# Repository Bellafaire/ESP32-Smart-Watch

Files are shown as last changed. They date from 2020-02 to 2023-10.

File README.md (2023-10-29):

# ESP32 Smartwatch
This project is a fully open source smartwatch based around the ESP32, the project is ongoing for updates see the hackaday.io page for this project (https://hackaday.io/project/168227-custom-smartwatch).
The goal of this project is to create a smartwatch that is easy to reprogram and use as an IOT controller or just as a DIY fashion statement.  
Serial communication and charging are handled on-board through a single micro-usb connector without any external dock. 
The watch is built around the ESP32 WROOM module and is programable using the espressif or Arduino IDE. 
Using the ESP32 allows for the user to develop their software while leveraging the open-source libraries and examples that are available online for quick development.

## Companion App 
The companion android app that allows the smartwatch to control media and obtain phone notifications has been split to a seperate repo and can be found [here](https://github.com/Bellafaire/Android-Companion-App-For-BLE-Devices) along with an example sketch for bluetooth interfacing using the ESP32. 
The app can be downloaded from the releases tab of the provided repo, the V1 watch firmware works only with app releases up to 1.2.0. 
For firmware versions 2 and 3 releases after 2.0.0 must be used, releases after this version use a different communication structure that has proved to be more reliable. 

## Firmware Versions
There are 3 versions of the firmware available for this project. Only V3 is in active development. 
The V1 firmware utilizes deep sleep along with the V1 android companion app, this firmware works well enough and offers the greatest power savings over any of the other options. 
V2 is a bit more animated, boasting some additional applications along with the switch to light sleep which enables faster wakeup from tap or by performing a wrist gesture. 

V3 is the current firmware, it is much more stable and expandable. 
The current V3 firmware supports: 
- App icons on home screen, tap to view the tagline of the notification
- Spotify control through tapping the spotify app icon
- built in calculator 
- Improved UI and tools to aid feature expansion. 

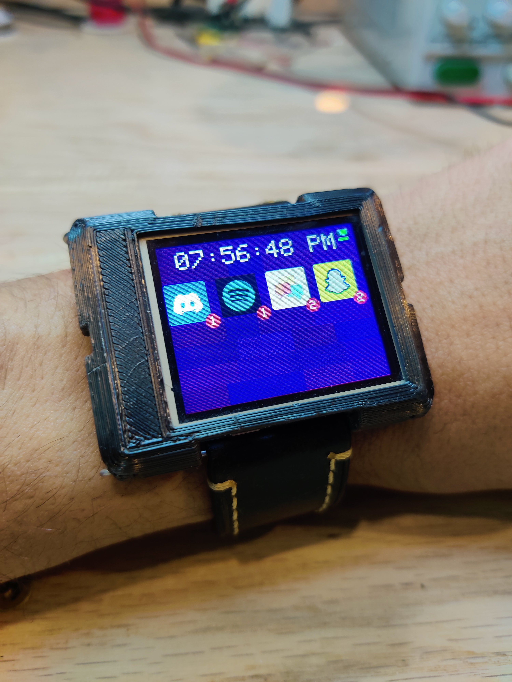
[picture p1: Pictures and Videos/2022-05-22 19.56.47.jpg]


The case is 3D printed and designed in FreeCAD, the design files are available in this repo. 

### Dependencies 
If you're working with the V3 Firmware, then you will need the following dependencies, you can get these through the Arduino IDE library manager: 
- Adafruit GFX Version 1.11.9 By Adafruit
- Adafruit ST7735 and ST7789 Library Version 1.10.3 By Adafruit
- base64 Version 1.30 by Densaugeo 

Other versions of the above dependencies **will most likely work** but have not been tested on this hardware. 

## Hardware Versions
The current hardware version for the watch is V5 which provides a more slim design while maintaining all the features of V4. 

## Video Updates about the project

[Video Update #5](https://www.youtube.com/watch?v=LVs-HgjjFUM)

[Video Update #4](https://www.youtube.com/watch?v=E8-lO0pQunM)

[Video Update #3](https://www.youtube.com/watch?v=vvuce4NQqrk)

[Video Update #2](https://www.youtube.com/watch?v=UNLAq5FuJq4)

[Video Update #1](https://www.youtube.com/watch?v=IoVqdB_q3pE)

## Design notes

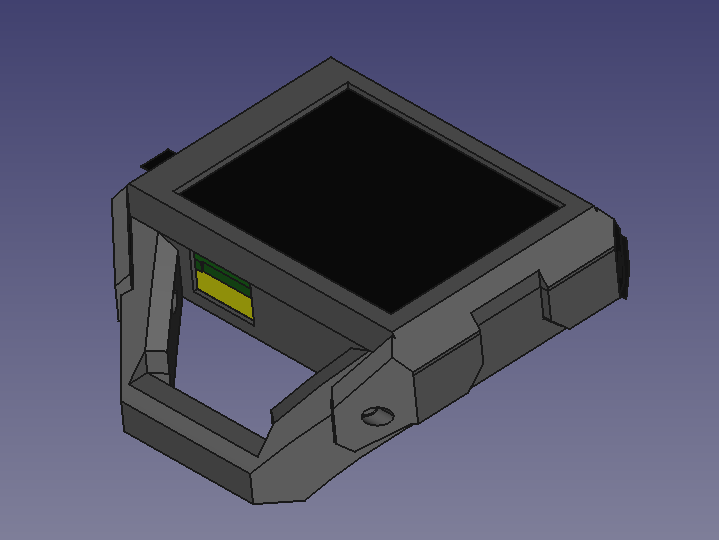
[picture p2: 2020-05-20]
Pictures and Videos/smartwatch V4 Case.png

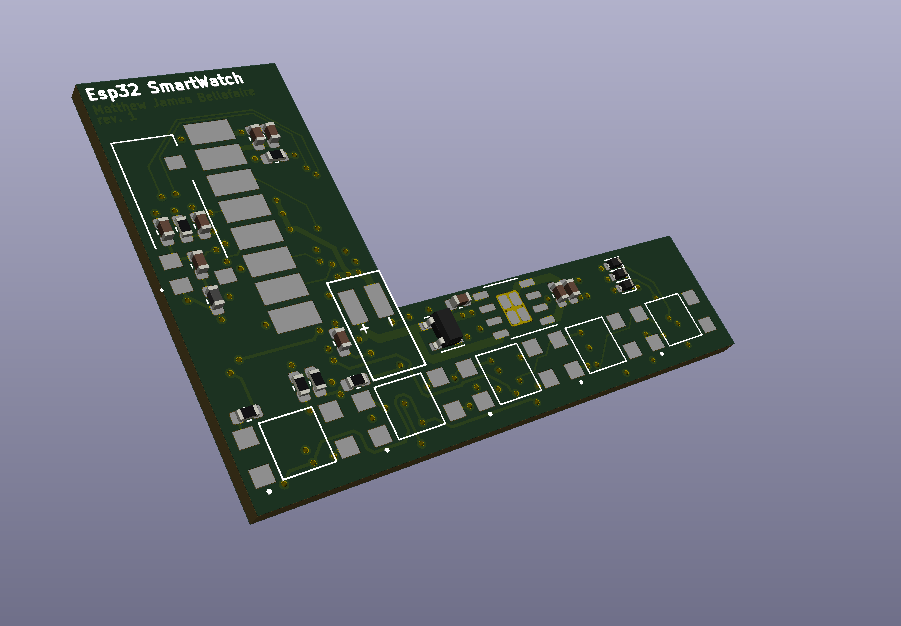
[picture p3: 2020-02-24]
Pictures and Videos/Screenshot_1.png

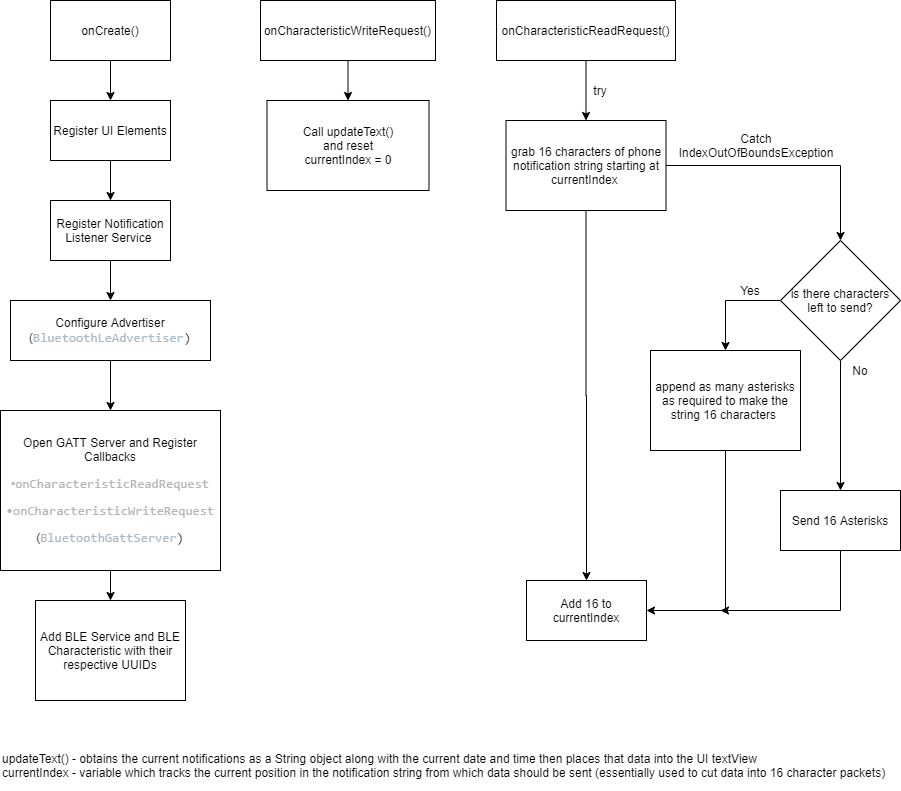
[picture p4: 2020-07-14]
Pictures and Videos/Android App GATT Flowchart.png

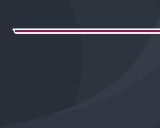
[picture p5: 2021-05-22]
Misc. Files/BACKGROUND.png

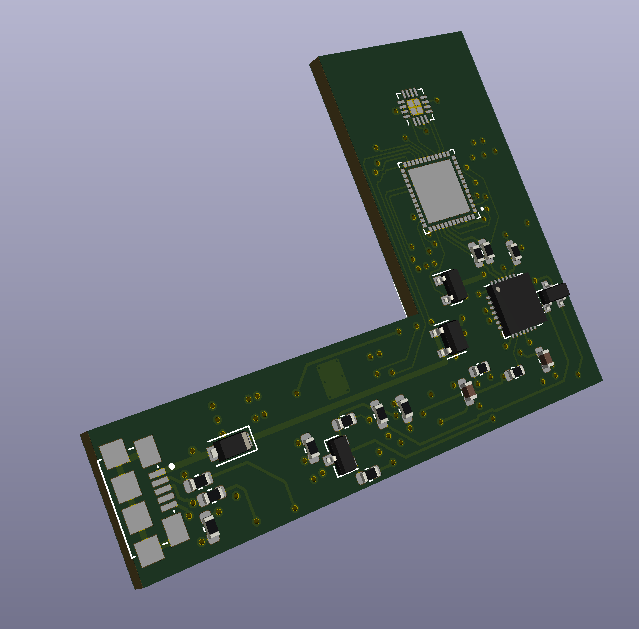
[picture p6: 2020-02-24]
Pictures and Videos/Screenshot_2.png

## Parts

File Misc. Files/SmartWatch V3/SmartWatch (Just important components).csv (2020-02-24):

Qty | Reference(s) | Value | LibPart | Footprint | Datasheet | DigiKey Part Number
1 | ANT1 | W3008 | SmartWatch-rescue:W3008 | SmartWatch:ANTENNA_W3008 | Manufacturer recommendations | 553-1530-1-ND
2 | C1, C2 | 10nF | Device:C | Capacitor_SMD:C_0603_1608Metric | ~ | 399-7842-1-ND
25 | C3, C20 | 10uF | Device:C | Capacitor_SMD:C_0603_1608Metric | ~ | 478-10766-1-ND
50 | C5, C7, C9, C11, C15, C16, C17, C18, C19 | 0.1u | Device:C | Capacitor_SMD:C_0603_1608Metric | ~ | 1276-1258-1-ND
3 | ESP1 | ESP32PICO_D4-esp32pico_d4 | SmartWatch-rescue:ESP32PICO_D4-esp32pico_d4 | SmartWatch:ESP32_D4_PICO_HAND_SOLDER |  | 1904-1029-1-ND
50 | Q1, Q2 | MMBT3904 | Transistor_BJT:MMBT3904 | Package_TO_SOT_SMD:SOT-23 | https://www.fairchildsemi.com/datasheets/2N/2N3904.pdf | MMBT3904TPMSCT-ND
6 | R1, R2, R3, R4, R8, R19 | 0R | Device:R | Resistor_SMD:R_0603_1608Metric | ~ | 311-0.0GRCT-ND
8 | R5, R6, R7, R11, R13, R14, R15, R16 | 10k | Device:R | Resistor_SMD:R_0603_1608Metric | ~ | 311-10KGRCT-ND
2 | R9, R10 | 27 | Device:R | Resistor_SMD:R_0603_1608Metric | ~ | 311-27.0HRCT-ND
1 | R12 | 47k | Device:R | Resistor_SMD:R_0603_1608Metric | ~ | 311-47GRCT-ND
10 | SW1, SW2 | EVQ-P7J01P | SmartWatch-rescue:EVQ-P7J01P | SmartWatch:SW_EVQ-P7J01P | Panasonic | P16767CT-ND
2 | U1 | S-13A1A33-E8T1U3 | SmartWatch-rescue:S-13A1A33-E8T1U3 | Package_SO:HSOP-8-1EP_3.9x4.9mm_P1.27mm_EP2.41x3.1mm_ThermalVias | https://www.ablic.com/en/doc/datasheet/voltage_regulator/S13A1_E.pdf | 1662-2801-1-ND
3 | U3 | FT231XS | Interface_USB:FT231XS | Package_SO:SSOP-20_3.9x8.7mm_P0.635mm | http://www.ftdichip.com/Products/ICs/FT231X.html | 768-1129-1-ND

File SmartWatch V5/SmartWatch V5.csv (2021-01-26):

Item | Qty | Reference(s) | Value | LibPart | Footprint | Datasheet | Field4 | Field5 | Field6 | Field7 | Field8 | digikey
1 | 1 | A1 | ZJY117 | CustomParts:ZJY117 | CustomFootprints:ZJY117 | https://www.icbanq.com/icdownload/data/ICBShop/Board/ZJY117-1.8_18P%20TFT%20LCD%20With%20Touch%20Panel.pdf
2 | 11 | C1, C4, C5, C6, C7, C9, C10, C12, C13, C14, C15 | 10uF | Device:C | Capacitor_SMD:C_0603_1608Metric | ~ |  |  |  |  |  | 478-10766-1-ND
3 | 4 | C2, C3, C8, C11 | 0.1uF | Device:C | Capacitor_SMD:C_0603_1608Metric | ~ |  |  |  |  |  | 1276-1006-1-ND
4 | 1 | D1 | FSV340FP | Device:D_Schottky | Diode_SMD:D_SOD-123 | https://www.onsemi.com/pub/Collateral/FSV360FP-D.PDF |  |  |  |  |  | FSV340FPCT-ND
5 | 3 | D2, D3, D4 | ESDZV5-1BF4 | Device:D_TVS | Diode_SMD:D_0201_0603Metric | https://www.st.com/content/ccc/resource/technical/document/datasheet/group3/3b/a1/d0/ee/47/bb/49/64/DM00344091/files/DM00344091.pdf/jcr:content/translations/e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 |  |  |  |  |  | 497-17318-1-ND
6 | 1 | J1 | 10118192-0001LF | CustomParts:10118192-0001LF | CustomFootprints:AMPHENOL_10118192-0001LF | Amphenol ICC | None | Single Port 5 Contact Horizontal Right Angle Shielded Micro B USB 2.0 Connector | 609-4613-1-ND | 10118192-0001LF | https://www.digikey.com/product-detail/en/amphenol-icc-fci/10118192-0001LF/609-4613-1-ND/2785378 | 609-4613-1-ND
7 | 1 | J2 |  | Connector:Conn_01x02_Female | CustomFootprints:BATTERY | ~
8 | 3 | J8, J9, J10 | TestPad | CustomParts:TestPad | CustomFootprints:TESTPAD
9 | 1 | Q1 | FDN340P | Device:Q_PMOS_GSD | Package_TO_SOT_SMD:SOT-23 | https://www.onsemi.com/pub/Collateral/FDN340P-D.PDF |  |  |  |  |  | FDN340PCT-ND
10 | 2 | Q2, Q3 | MMBT3904 | Device:Q_NPN_BEC | Package_TO_SOT_SMD:SOT-23 | https://assets.nexperia.com/documents/data-sheet/MMBT3904.pdf |  |  |  |  |  | 1727-4044-1-ND
11 | 2 | Q5, Q6 | FDN028N20 | Device:Q_NMOS_GSD | Package_TO_SOT_SMD:SOT-23 | https://www.onsemi.com/pub/Collateral/FDN028N20-D.pdf |  |  |  |  |  | FDN028N20OSCT-ND
12 | 3 | R1, R7, R21 | 100k | Device:R | Resistor_SMD:R_0603_1608Metric | ~ |  |  |  |  |  | CR0603-JW-104ELFCT-ND
13 | 2 | R2, R3 | 27 | Device:R | Resistor_SMD:R_0603_1608Metric | ~ |  |  |  |  |  | RMCF0603JT27R0CT-ND
14 | 13 | R6, R9, R10, R13, R14, R15, R16, R17, R18, R19, R20, R22, R24 | 10k | Device:R | Resistor_SMD:R_0603_1608Metric | ~ |  |  |  |  |  | 311-10.0KCRCT-ND
15 | 1 | R8 | 0 (NC) | Device:R | Resistor_SMD:R_0603_1608Metric | ~ |  |  |  |  |  | 311-0.0GRCT-ND
16 | 1 | R23 | 10m | Device:R | Resistor_SMD:R_0805_2012Metric | https://d1d2qsbl8m0m72.cloudfront.net/en/products/databook/datasheet/passive/resistor/chip_resistor/pmr-e.pdf |  |  |  |  |  | RL12T.010JCT-ND
17 | 2 | SW1, SW2 | EVQ-P7J01P | CustomParts:EVQ-P7J01P | CustomFootprints:SW_EVQ-P7J01P | Panasonic | Manufacturer Recommendation |  |  |  |  | P16767CT-ND
18 | 1 | TH1 | NXFT15XH103FA2B100 | Device:Thermistor | Connector_PinHeader_1.00mm:PinHeader_1x02_P1.00mm_Vertical | https://www.murata.com/~/media/webrenewal/support/library/catalog/products/thermistor/ntc/r44e.ashx?la=en-us |  |  |  |  |  | 490-5630-ND
19 | 1 | U1 | MAX17260 | CustomParts:MAX17260 | CustomFootprints:TDFN16-EP | https://datasheets.maximintegrated.com/en/ds/MAX17260.pdf |  |  |  |  |  | 175-MAX17260SEWL+TCT-ND
20 | 1 | U2 | FT231XQ | Interface_USB:FT231XQ | Package_DFN_QFN:QFN-20-1EP_4x4mm_P0.5mm_EP2.5x2.5mm | https://www.ftdichip.com/Support/Documents/DataSheets/ICs/DS_FT231X.pdf |  |  |  |  |  | 768-1128-1-ND
21 | 1 | U3 | LP5912-3.3DRVT | CustomParts:LP5912-3.3DRVT | Package_SON:WSON-6-1EP_2x2mm_P0.65mm_EP1x1.6mm_ThermalVias | http://www.ti.com/lit/ds/symlink/lp5912.pdf |  |  |  |  |  | 296-44153-1-ND
22 | 1 | U5 | MCP73832-2-OT | Battery_Management:MCP73832-2-OT | Package_TO_SOT_SMD:SOT-23-5 | http://ww1.microchip.com/downloads/en/DeviceDoc/20001984g.pdf |  |  |  |  |  | MCP73832T-2ACI/OTCT-ND
23 | 1 | U6 | ESP32-WROOM-32 | RF_Module:ESP32-WROOM-32 | RF_Module:ESP32-WROOM-32 | https://www.espressif.com/sites/default/files/documentation/esp32-wroom-32_datasheet_en.pdf |  |  |  |  |  | 1904-1010-1-ND
24 | 1 | U8 | ADXL337 | CustomParts:ADXL337 | CustomFootprints:ADXL337BCPZ-RL | https://www.analog.com/media/en/technical-documentation/data-sheets/ADXL337.pdf |  |  |  |  |  | ADXL337BCPZ-RLCT-ND
25 | 1 | U10 | TSC2003IPWR | CustomParts:TSC2003IPWR | Package_SO:TSSOP-16_4.4x5mm_P0.65mm | http://www.ti.com/lit/ds/symlink/tsc2003.pdf |  |  |  |  |  | 296-14340-1-ND
26 | 1 |  | LP502030JH |  |  | https://www.jauch.com/downloadfile/5bf52a1a232e7aaef7e84c3116561e20c/250mah_-_lp502030jh_1s1p_2_wire_50mm.pdf |  |  |  |  |  | 1908-1353-ND

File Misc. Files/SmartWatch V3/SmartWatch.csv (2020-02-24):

Source: | J:\Dropbox\Dropbox\Lab Projects\Smart Watch\SmartWatch V3\SmartWatch.sch
Date: | 1/13/2020 8:32:21 AM
Tool: | Eeschema (5.0.1)-3
Generator: | C:\Program Files\KiCad\bin\scripting\plugins/bom_csv_grouped_by_value.py
Component Count: | 58
Individual Components:
Item | Qty | Reference(s) | Value | LibPart | Footprint | Datasheet | DigiKey Part Number | Field4 | Field5 | Field6 | Field7 | Field8 | digikey
 |  | ANT1 | W3008 | SmartWatch-rescue:W3008 | SmartWatch:ANTENNA_W3008 | Manufacturer recommendations |  | PulseLarsen Antennas |  |  |  |  | 553-1530-1-ND
 |  | C1 | 10nF | Device:C | Capacitor_SMD:C_0603_1608Metric | ~ | 399-7842-1-ND
 |  | C2 | 10nF | Device:C | Capacitor_SMD:C_0603_1608Metric | ~ | 399-7842-1-ND
 |  | C3 | 10uF | Device:C | Capacitor_SMD:C_0603_1608Metric | ~ | 478-10766-1-ND
 |  | C4 | 0.1uF | Device:C | Capacitor_SMD:C_0603_1608Metric | ~ | 1276-1258-1-ND
 |  | C5 | 0.1u | Device:C | Capacitor_SMD:C_0603_1608Metric | ~ | 1276-1258-1-ND
 |  | C6 | 0.1u (NC) | Device:C | Capacitor_SMD:C_0603_1608Metric | ~ | 1276-1258-1-ND
 |  | C7 | 0.1u | Device:C | Capacitor_SMD:C_0603_1608Metric | ~ | 1276-1258-1-ND
 |  | C8 | 47p | Device:C | Capacitor_SMD:C_0603_1608Metric | ~ | 311-1065-1-ND
 |  | C9 | 0.1u | Device:C | Capacitor_SMD:C_0603_1608Metric | ~ | 1276-1258-1-ND
 |  | C10 | 10u | Device:C | Capacitor_SMD:C_0603_1608Metric | ~ | 478-10766-1-ND
 |  | C11 | 0.1u | Device:C | Capacitor_SMD:C_0603_1608Metric | ~ | 1276-1258-1-ND
 |  | C12 | TBD | Device:C | Capacitor_SMD:C_0603_1608Metric | ~ | 1276-1258-1-ND
 |  | C13 | TBD | Device:C | Capacitor_SMD:C_0603_1608Metric | ~ | 1276-1258-1-ND
 |  | C14 | 47p | Device:C | Capacitor_SMD:C_0603_1608Metric | ~ | 311-1065-1-ND
 |  | C15 | 0.1u | Device:C | Capacitor_SMD:C_0603_1608Metric | ~ | 1276-1258-1-ND
 |  | C16 | 0.1u | Device:C | Capacitor_SMD:C_0603_1608Metric | ~ | 1276-1258-1-ND
 |  | C17 | 0.1u | Device:C | Capacitor_SMD:C_0603_1608Metric | ~ | 1276-1258-1-ND
 |  | C18 | 0.1u | Device:C | Capacitor_SMD:C_0603_1608Metric | ~ | 1276-1258-1-ND
 |  | C19 | 0.1u | Device:C | Capacitor_SMD:C_0603_1608Metric | ~ | 1276-1258-1-ND
 |  | C20 | 10uF | Device:C | Capacitor_SMD:C_0603_1608Metric | ~ | 478-10766-1-ND
 |  | D2 | FSV340FP | Device:D_Schottky | Diode_SMD:D_SOD-123F | https://www.onsemi.com/pub/Collateral/FSV360FP-D.PDF | FSV340FPCT-ND
 |  | ESP1 | ESP32PICO_D4-esp32pico_d4 | SmartWatch-rescue:ESP32PICO_D4-esp32pico_d4 | SmartWatch:ESP32_D4_PICO_HAND_SOLDER
 |  | J1 | 10118192-0001LF | SmartWatch-rescue:10118192-0001LF | SmartWatch:AMPHENOL_10118192-0001LF | Amphenol ICC | 609-4613-1-ND | None | Single Port 5 Contact Horizontal Right Angle Shielded Micro B USB 2.0 Connector | 609-4613-1-ND | 10118192-0001LF | https://www.digikey.com/product-detail/en/amphenol-icc-fci/10118192-0001LF/609-4613-1-ND/2785378
 |  | J2 | Bat_in | Connector:Conn_01x02_Female | SmartWatch:BATTERY | ~
 |  | J3 | TEST_PAD | SmartWatch-rescue:TEST_PAD | SmartWatch:TEST_PAD
 |  | J4 | TEST_PAD | SmartWatch-rescue:TEST_PAD | SmartWatch:TEST_PAD
 |  | J5 | TEST_PAD | SmartWatch-rescue:TEST_PAD | SmartWatch:TEST_PAD
 |  | J6 | TEST_PAD | SmartWatch-rescue:TEST_PAD | SmartWatch:TEST_PAD
 |  | L1 | TBD | Device:L | Inductor_SMD:L_0603_1608Metric | ~
 |  | Q1 | MMBT3904 | Transistor_BJT:MMBT3904 | Package_TO_SOT_SMD:SOT-23 | https://www.fairchildsemi.com/datasheets/2N/2N3904.pdf |  |  |  |  |  |  | MMBT3904TPMSCT-ND
 |  | Q2 | MMBT3904 | Transistor_BJT:MMBT3904 | Package_TO_SOT_SMD:SOT-23 | https://www.fairchildsemi.com/datasheets/2N/2N3904.pdf |  |  |  |  |  |  | MMBT3904TPMSCT-ND
 |  | Q3 | FDN340P | Device:Q_PMOS_DGS | Package_TO_SOT_SMD:SOT-23 | ~ | FDN340PCT-ND
 |  | R1 | 0R | Device:R | Resistor_SMD:R_0603_1608Metric | ~ | 311-0.0GRCT-ND
 |  | R2 | 0R | Device:R | Resistor_SMD:R_0603_1608Metric | ~ | 311-0.0GRCT-ND
 |  | R3 | 0R | Device:R | Resistor_SMD:R_0603_1608Metric | ~ | 311-0.0GRCT-ND
 |  | R4 | 0R | Device:R | Resistor_SMD:R_0603_1608Metric | ~ | 311-0.0GRCT-ND
 |  | R5 | 10k | Device:R | Resistor_SMD:R_0603_1608Metric | ~ | 311-10KGRCT-ND
 |  | R6 | 10k | Device:R | Resistor_SMD:R_0603_1608Metric | ~ | 311-10KGRCT-ND
 |  | R7 | 10k | Device:R | Resistor_SMD:R_0603_1608Metric | ~ | 311-10KGRCT-ND
 |  | R8 | 0R | Device:R | Resistor_SMD:R_0603_1608Metric | ~ | 311-0.0GRCT-ND
 |  | R9 | 27 | Device:R | Resistor_SMD:R_0603_1608Metric | ~ | 311-27.0HRCT-ND
 |  | R10 | 27 | Device:R | Resistor_SMD:R_0603_1608Metric | ~ | 311-27.0HRCT-ND
 |  | R11 | 10k | Device:R | Resistor_SMD:R_0603_1608Metric | ~ | 311-10KGRCT-ND
 |  | R12 | 47k | Device:R | Resistor_SMD:R_0603_1608Metric | ~ | 311-47GRCT-ND
 |  | R13 | 10k | Device:R | Resistor_SMD:R_0603_1608Metric | ~ | 311-10KGRCT-ND
 |  | R14 | 10k | Device:R | Resistor_SMD:R_0603_1608Metric | ~ | 311-10KGRCT-ND
 |  | R15 | 10k | Device:R | Resistor_SMD:R_0603_1608Metric | ~ | 311-10KGRCT-ND
 |  | R16 | 10k | Device:R | Resistor_SMD:R_0603_1608Metric | ~ | 311-10KGRCT-ND
 |  | R19 | 0R | Device:R | Resistor_SMD:R_0603_1608Metric | ~ | 311-0.0GRCT-ND
 |  | SW1 | EVQ-P7J01P | SmartWatch-rescue:EVQ-P7J01P | SmartWatch:SW_EVQ-P7J01P | Panasonic |  | Manufacturer Recommendation |  |  |  |  | P16767CT-ND
 |  | SW2 | EVQ-P7J01P | SmartWatch-rescue:EVQ-P7J01P | SmartWatch:SW_EVQ-P7J01P | Panasonic |  | Manufacturer Recommendation |  |  |  |  | P16767CT-ND
 |  | U1 | S-13A1A33-E8T1U3 | SmartWatch-rescue:S-13A1A33-E8T1U3 | Package_SO:HSOP-8-1EP_3.9x4.9mm_P1.27mm_EP2.41x3.1mm_ThermalVias | https://www.ablic.com/en/doc/datasheet/voltage_regulator/S13A1_E.pdf | 1662-2801-1-ND
 |  | U2 | LCD_TOUCH | SmartWatch-rescue:LCD_TOUCH | Connector_PinHeader_2.54mm:PinHeader_2x06_P2.54mm_Vertical | https://usa.banggood.com/1_8-Inch-LCD-Screen-SPI-Serial-Port-Module-TFT-Color-Display-Touch-Screen-ST7735-For-Arduino-p-1414465.html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
 |  | U3 | FT231XS | Interface_USB:FT231XS | Package_SO:SSOP-20_3.9x8.7mm_P0.635mm | http://www.ftdichip.com/Products/ICs/FT231X.html |  |  |  |  |  |  | 768-1129-1-ND
 |  | U4 | MAX9065 | SmartWatch-rescue:MAX9065 | Package_TO_SOT_SMD:SOT-23-5 | https://datasheets.maximintegrated.com/en/ds/MAX9065.pdf | MAX9065EUK+TCT-ND
 |  | U5 | MCP73811T-420I-OT | Battery_Management:MCP73811T-420I-OT | Package_TO_SOT_SMD:SOT-23-5 | http://ww1.microchip.com/downloads/en/DeviceDoc/22036b.pdf | MCP73811T-420I/OTCT-ND
 |  | U7 | ADXL337 | SmartWatch-rescue:ADXL337 | SmartWatch:LFCSP-16-1EP_3x3mm_P0.5mm_EP1.6x1.6mm | https://www.analog.com/media/en/technical-documentation/data-sheets/ADXL337.pdf | ADXL337BCPZ-RL7CT-ND
Collated Components:
Item | Qty | Reference(s) | Value | LibPart | Footprint | Datasheet | DigiKey Part Number | Field4 | Field5 | Field6 | Field7 | Field8 | digikey
1 | 1 | ANT1 | W3008 | SmartWatch-rescue:W3008 | SmartWatch:ANTENNA_W3008 | Manufacturer recommendations |  | PulseLarsen Antennas |  |  |  |  | 553-1530-1-ND
2 | 2 | C1, C2 | 10nF | Device:C | Capacitor_SMD:C_0603_1608Metric | ~ | 399-7842-1-ND
3 | 2 | C3, C20 | 10uF | Device:C | Capacitor_SMD:C_0603_1608Metric | ~ | 478-10766-1-ND
4 | 1 | C4 | 0.1uF | Device:C | Capacitor_SMD:C_0603_1608Metric | ~ | 1276-1258-1-ND
5 | 9 | C5, C7, C9, C11, C15, C16, C17, C18, C19 | 0.1u | Device:C | Capacitor_SMD:C_0603_1608Metric | ~ | 1276-1258-1-ND
6 | 1 | C6 | 0.1u (NC) | Device:C | Capacitor_SMD:C_0603_1608Metric | ~ | 1276-1258-1-ND
7 | 2 | C8, C14 | 47p | Device:C | Capacitor_SMD:C_0603_1608Metric | ~ | 311-1065-1-ND
8 | 1 | C10 | 10u | Device:C | Capacitor_SMD:C_0603_1608Metric | ~ | 478-10766-1-ND
9 | 2 | C12, C13 | TBD | Device:C | Capacitor_SMD:C_0603_1608Metric | ~ | 1276-1258-1-ND
10 | 1 | D2 | FSV340FP | Device:D_Schottky | Diode_SMD:D_SOD-123F | https://www.onsemi.com/pub/Collateral/FSV360FP-D.PDF | FSV340FPCT-ND
11 | 1 | ESP1 | ESP32PICO_D4-esp32pico_d4 | SmartWatch-rescue:ESP32PICO_D4-esp32pico_d4 | SmartWatch:ESP32_D4_PICO_HAND_SOLDER
12 | 1 | J1 | 10118192-0001LF | SmartWatch-rescue:10118192-0001LF | SmartWatch:AMPHENOL_10118192-0001LF | Amphenol ICC | 609-4613-1-ND | None | Single Port 5 Contact Horizontal Right Angle Shielded Micro B USB 2.0 Connector | 609-4613-1-ND | 10118192-0001LF | https://www.digikey.com/product-detail/en/amphenol-icc-fci/10118192-0001LF/609-4613-1-ND/2785378
13 | 1 | J2 | Bat_in | Connector:Conn_01x02_Female | SmartWatch:BATTERY | ~
14 | 4 | J3, J4, J5, J6 | TEST_PAD | SmartWatch-rescue:TEST_PAD | SmartWatch:TEST_PAD
15 | 1 | L1 | TBD | Device:L | Inductor_SMD:L_0603_1608Metric | ~
16 | 2 | Q1, Q2 | MMBT3904 | Transistor_BJT:MMBT3904 | Package_TO_SOT_SMD:SOT-23 | https://www.fairchildsemi.com/datasheets/2N/2N3904.pdf |  |  |  |  |  |  | MMBT3904TPMSCT-ND
17 | 1 | Q3 | FDN340P | Device:Q_PMOS_DGS | Package_TO_SOT_SMD:SOT-23 | ~ | FDN340PCT-ND
18 | 6 | R1, R2, R3, R4, R8, R19 | 0R | Device:R | Resistor_SMD:R_0603_1608Metric | ~ | 311-0.0GRCT-ND
19 | 8 | R5, R6, R7, R11, R13, R14, R15, R16 | 10k | Device:R | Resistor_SMD:R_0603_1608Metric | ~ | 311-10KGRCT-ND
20 | 2 | R9, R10 | 27 | Device:R | Resistor_SMD:R_0603_1608Metric | ~ | 311-27.0HRCT-ND
21 | 1 | R12 | 47k | Device:R | Resistor_SMD:R_0603_1608Metric | ~ | 311-47GRCT-ND
22 | 2 | SW1, SW2 | EVQ-P7J01P | SmartWatch-rescue:EVQ-P7J01P | SmartWatch:SW_EVQ-P7J01P | Panasonic |  | Manufacturer Recommendation |  |  |  |  | P16767CT-ND
23 | 1 | U1 | S-13A1A33-E8T1U3 | SmartWatch-rescue:S-13A1A33-E8T1U3 | Package_SO:HSOP-8-1EP_3.9x4.9mm_P1.27mm_EP2.41x3.1mm_ThermalVias | https://www.ablic.com/en/doc/datasheet/voltage_regulator/S13A1_E.pdf | 1662-2801-1-ND
24 | 1 | U2 | LCD_TOUCH | SmartWatch-rescue:LCD_TOUCH | Connector_PinHeader_2.54mm:PinHeader_2x06_P2.54mm_Vertical | https://usa.banggood.com/1_8-Inch-LCD-Screen-SPI-Serial-Port-Module-TFT-Color-Display-Touch-Screen-ST7735-For-Arduino-p-1414465.html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
25 | 1 | U3 | FT231XS | Interface_USB:FT231XS | Package_SO:SSOP-20_3.9x8.7mm_P0.635mm | http://www.ftdichip.com/Products/ICs/FT231X.html |  |  |  |  |  |  | 768-1129-1-ND
26 | 1 | U4 | MAX9065 | SmartWatch-rescue:MAX9065 | Package_TO_SOT_SMD:SOT-23-5 | https://datasheets.maximintegrated.com/en/ds/MAX9065.pdf | MAX9065EUK+TCT-ND
27 | 1 | U5 | MCP73811T-420I-OT | Battery_Management:MCP73811T-420I-OT | Package_TO_SOT_SMD:SOT-23-5 | http://ww1.microchip.com/downloads/en/DeviceDoc/22036b.pdf | MCP73811T-420I/OTCT-ND
28 | 1 | U7 | ADXL337 | SmartWatch-rescue:ADXL337 | SmartWatch:LFCSP-16-1EP_3x3mm_P0.5mm_EP1.6x1.6mm | https://www.analog.com/media/en/technical-documentation/data-sheets/ADXL337.pdf | ADXL337BCPZ-RL7CT-ND

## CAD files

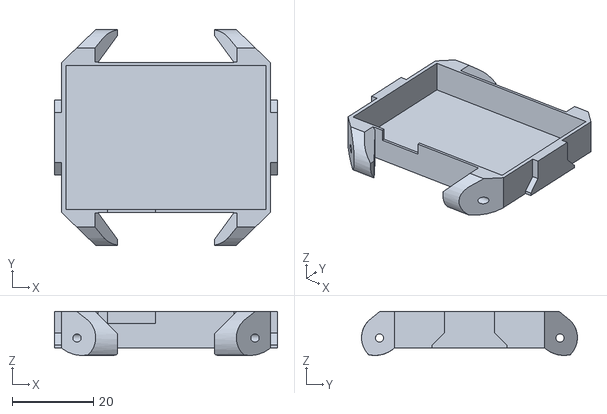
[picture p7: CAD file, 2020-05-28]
Misc. Files/4.1 Bottom.stl
55.0 x 53.3 x 10.9

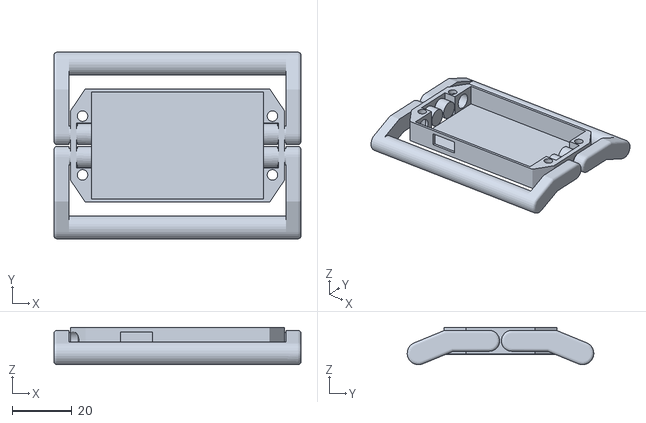
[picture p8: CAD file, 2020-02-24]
Misc. Files/SmartWatch V3/body.stl
82.5 x 62.4 x 12.5

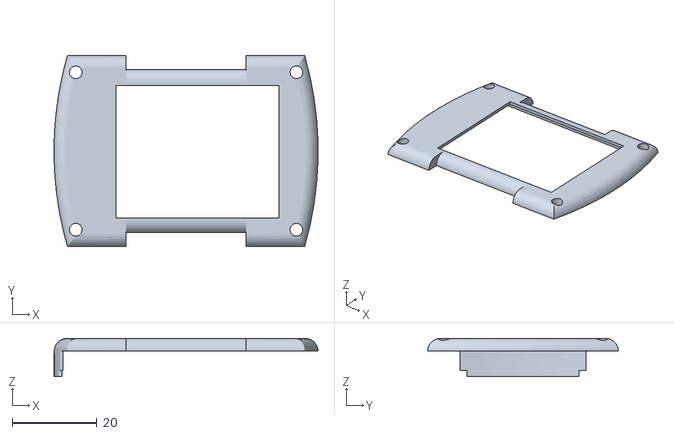
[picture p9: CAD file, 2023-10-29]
Smartwatch Rev 5 Case 2 Top.stl
62.3 x 45.0 x 9.00

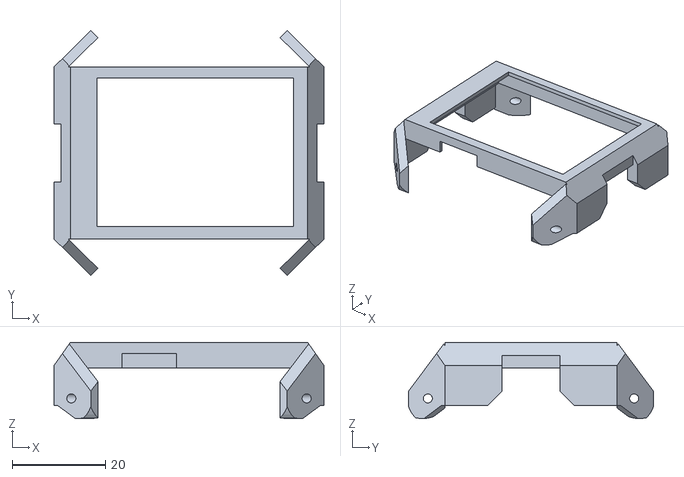
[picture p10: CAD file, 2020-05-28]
Misc. Files/4.1 Top.stl
58.0 x 52.6 x 16.4

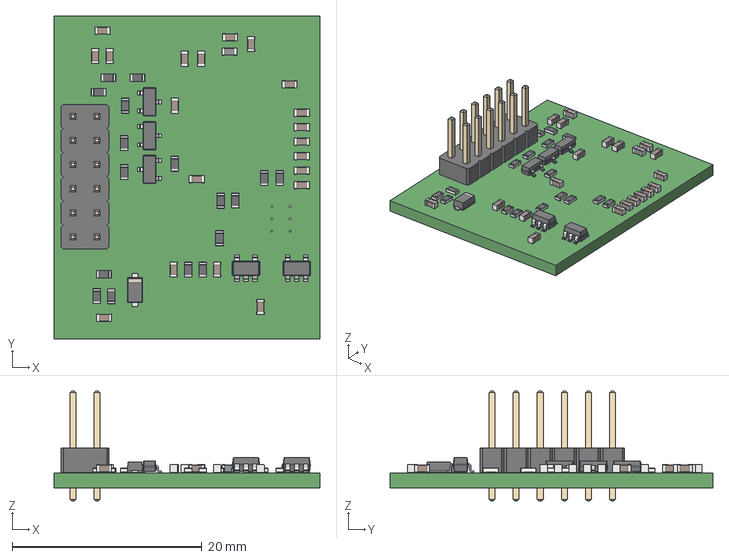
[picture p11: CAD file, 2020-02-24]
Misc. Files/SmartWatch V3/SmartWatch.step
28.0 x 34.0 x 11.5 mm

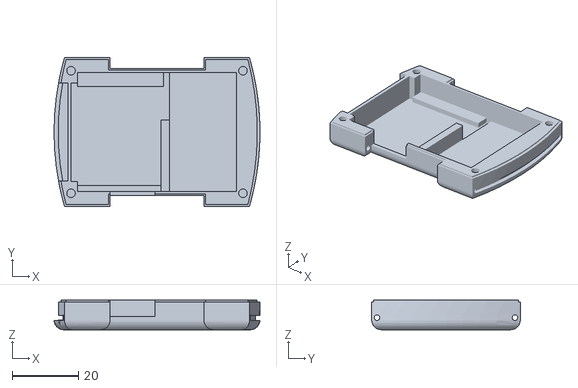
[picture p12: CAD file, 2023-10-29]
SmartWatch Rev 5 Case 2 Bottom.stl
62.4 x 45.0 x 9.00

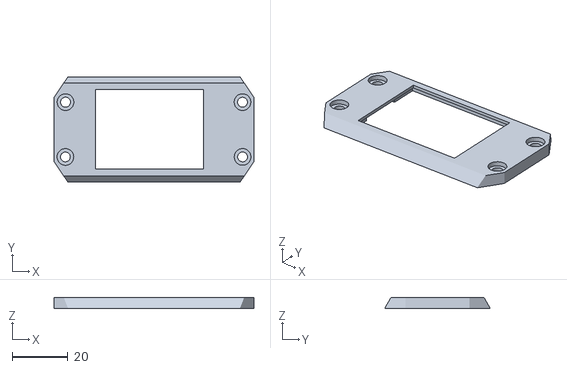
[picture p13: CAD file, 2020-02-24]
Misc. Files/SmartWatch V3/top.stl
71.6 x 37.8 x 4.00

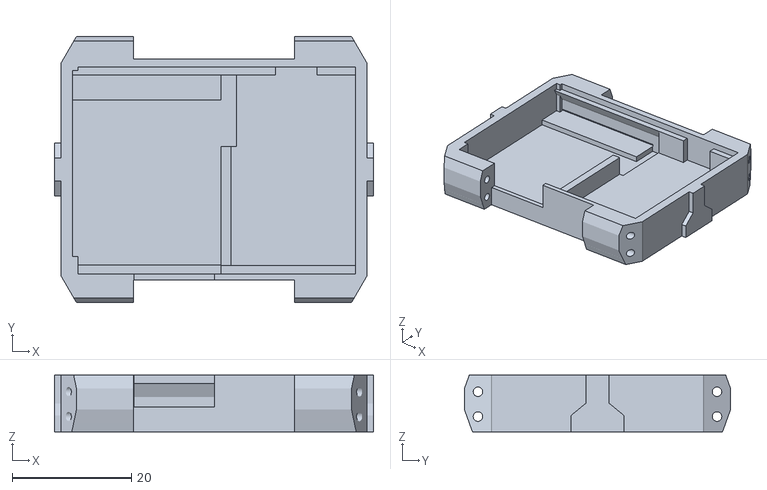
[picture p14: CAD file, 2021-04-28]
Rev 5 Bottom.stl
53.6 x 44.7 x 9.50

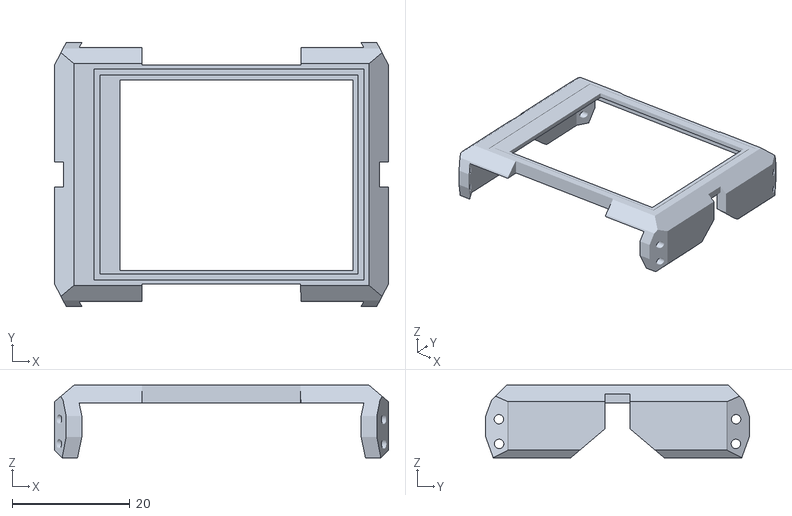
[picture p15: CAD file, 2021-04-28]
Rev 5 Top.stl
56.6 x 44.7 x 12.3

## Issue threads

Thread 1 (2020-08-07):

Splitting ESP32-Smart-Watch repository

FedericoBusero, 2020-08-07:
Hi,

This is a great project you just did. I'd like to use the Android app and smartwatch firmware on my ESP32-based smartwatch. I guess the Android app and firmware can be made device independant (supporting different types of displays & accelerometers).

It would be great if you could split up (and remove old files) into 3 repositories:
1) Android app
2) Smartwatch ESP32 firmware
3) Your hardware

I am convinced, that this project can become widely used.

Bellafaire, 2020-08-08:
Thanks for the feedback, I do have plans to split the android app to its own repository since I know it could be of use to others working on similar projects. Before I do that however I want to do some clean up of the code and put together a better implementation of BLE communication on the ESP32 side of things so I can provide some example sketches and generally polish up the app as a communication method to the ESP32.

As for the hardware and firmware I don't really have any plans to split them up since they're essentially two parts of the same whole. At some point in the future I do plan to make the smartwatch firmware compatible with the T-Watch-2020 since it's a popular ESP32 based device that's mostly compatible with this project. In the process of that the code will become easier to move between platforms since the majority of the hardware interfacing will be functionalized.

Bellafaire, 2020-08-12:
The android companion app has now been forked to a new repo along with an example sketch for anyone who wants to use it with the ESP32 https://github.com/Bellafaire/Android-Companion-App-For-BLE-Devices

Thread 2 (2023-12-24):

Does ESP32-Smart-Watch support cam, like ESP32 Cam OV5640, or any cam ? Thank you.

selfhostrepo, 2023-12-24:
Does ESP32-Smart-Watch support cam, like ESP32 Cam OV5640, or any cam ? Thank you.

Bellafaire, 2023-12-24:
Unfortunately it does not. I'm not sure that the OV5640 could be added to this project given its requirements for GPIO. This project uses almost every available GPIO pin available on the ESP32. A camera that relied on the I2C bus might be able to be integrated but that's about it.

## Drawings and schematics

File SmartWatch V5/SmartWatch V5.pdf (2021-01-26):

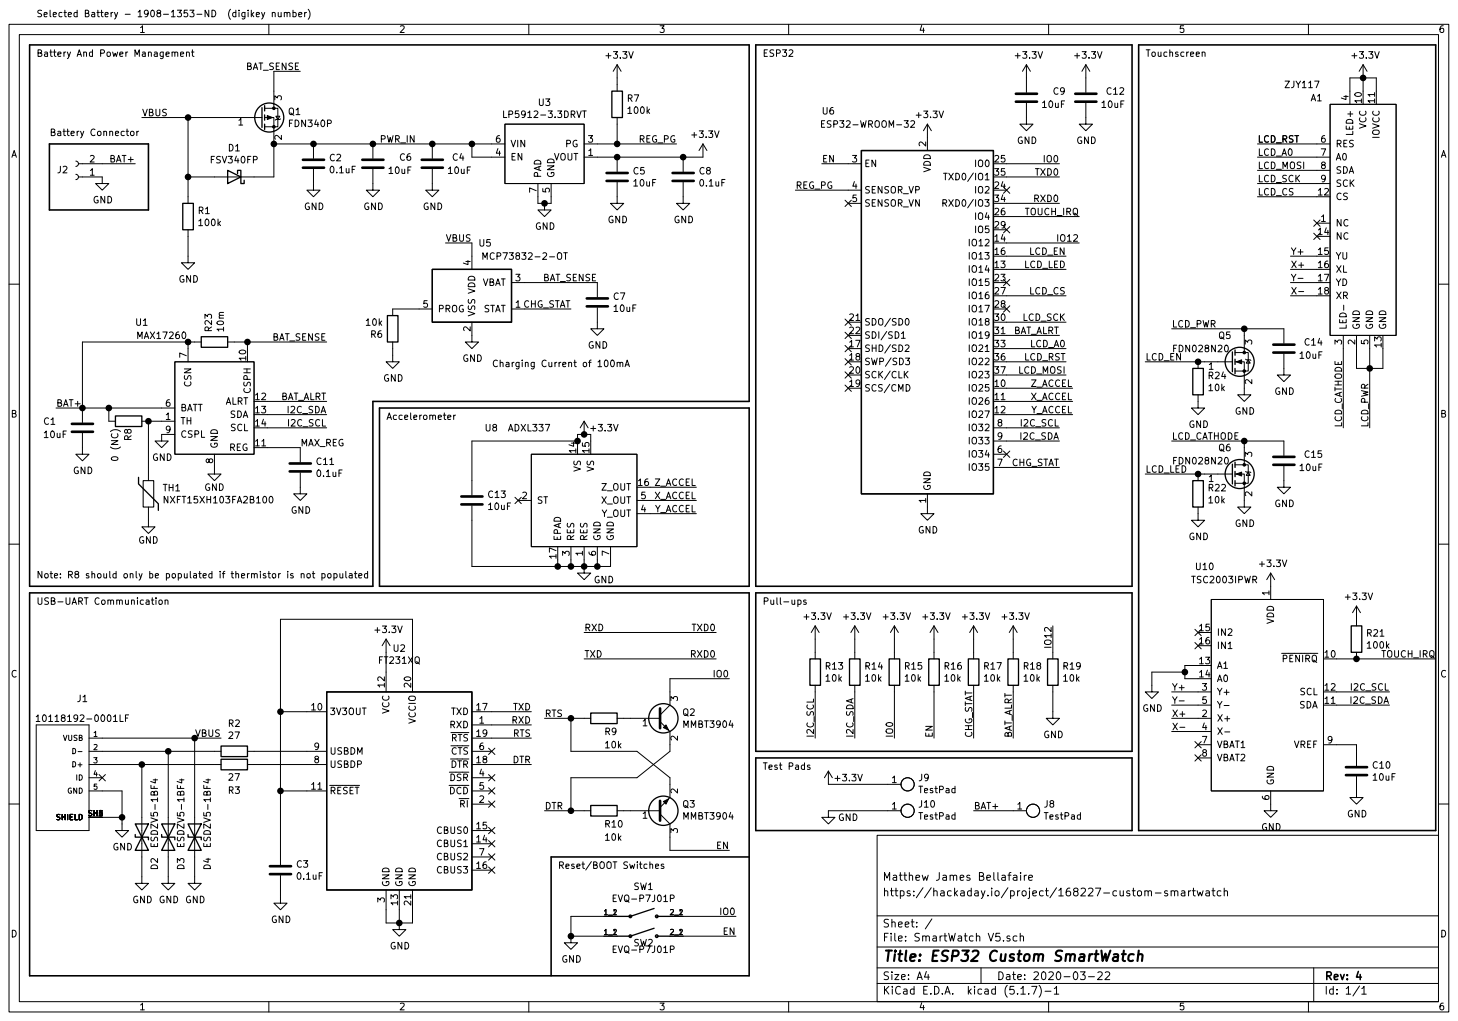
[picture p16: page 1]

ESP32 Accelerometer Selected Battery - 1908-1353-ND (digikey number)

7 U8 ADXL337 NC 1 VCC 10 IOVCC 11 CS 12 GND 13 NC 14 YU 15 XL 16 YD 17 XR 18 GND
10uF GND

2 SCK/CLK 20 SDO/SD0 21 SDI/SD1 22

Charging Current of 100mA USB-UART Communication

1 VS 14 VS 15 Z_OUT 16 EPAD 17 ST 2 RES

Test Pads Note: R8 should only be populated if thermistor is not populated

3 DSR 4 DCD 5 CTS 6 CBUS2 7 USBDP 8 USBDM 9 U2 FT231XQ

Id: 1/1 Title: ESP32 Custom SmartWatch

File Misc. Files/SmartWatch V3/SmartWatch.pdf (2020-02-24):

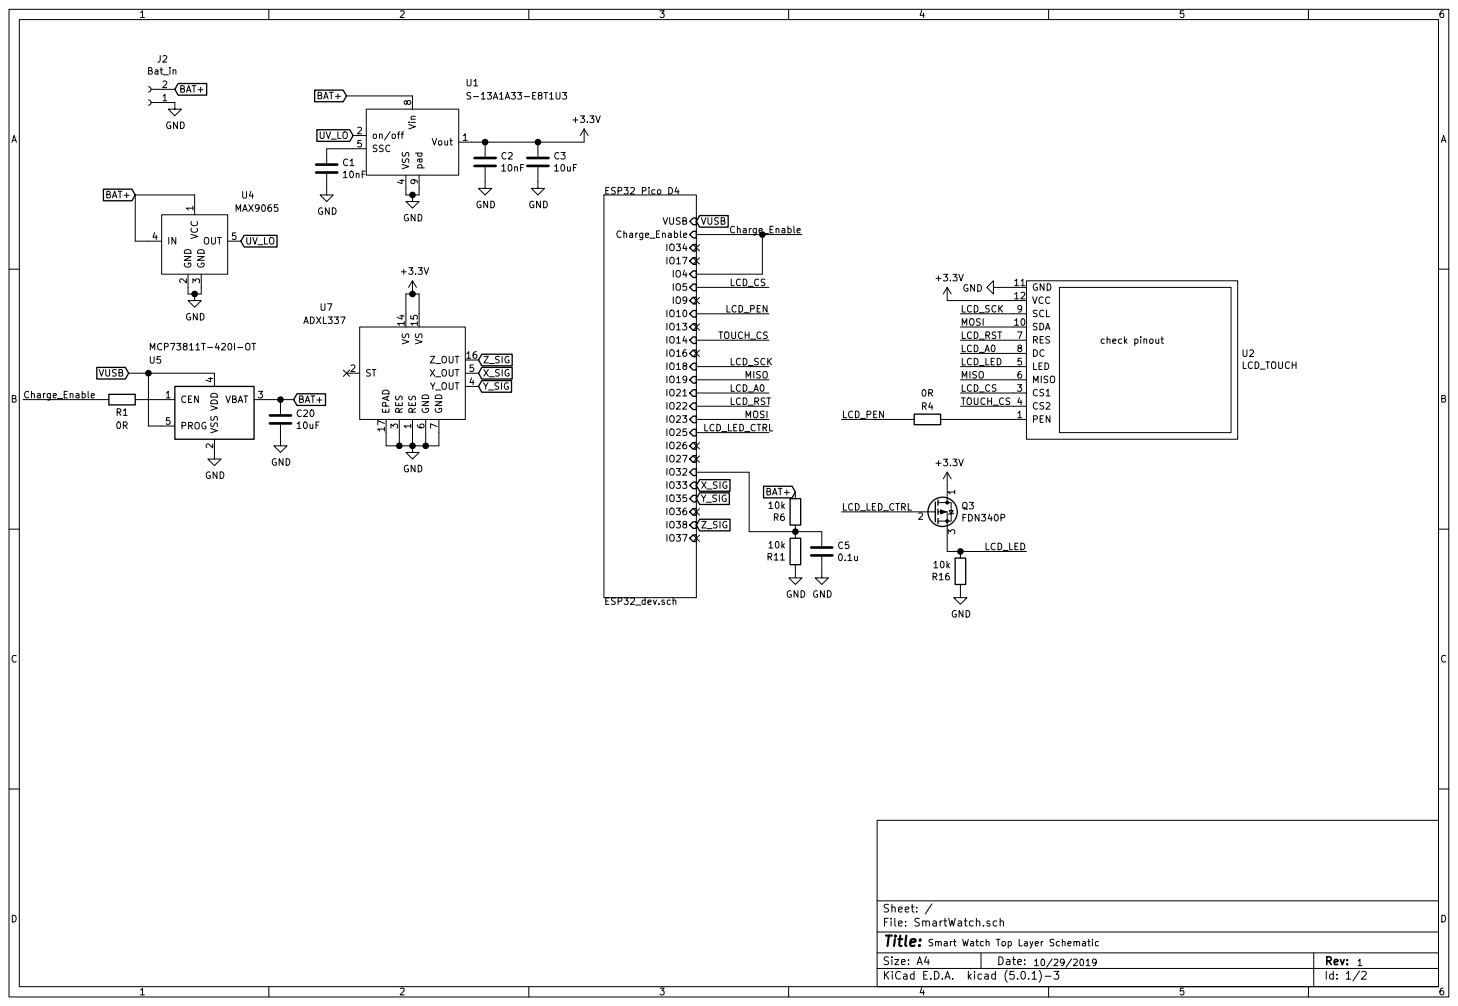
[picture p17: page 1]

1 VS 14 VS 15 Z_OUT 16 EPAD 17 ST 2 RES

Id: 1/2 Title: File: SmartWatch.sch Sheet: /

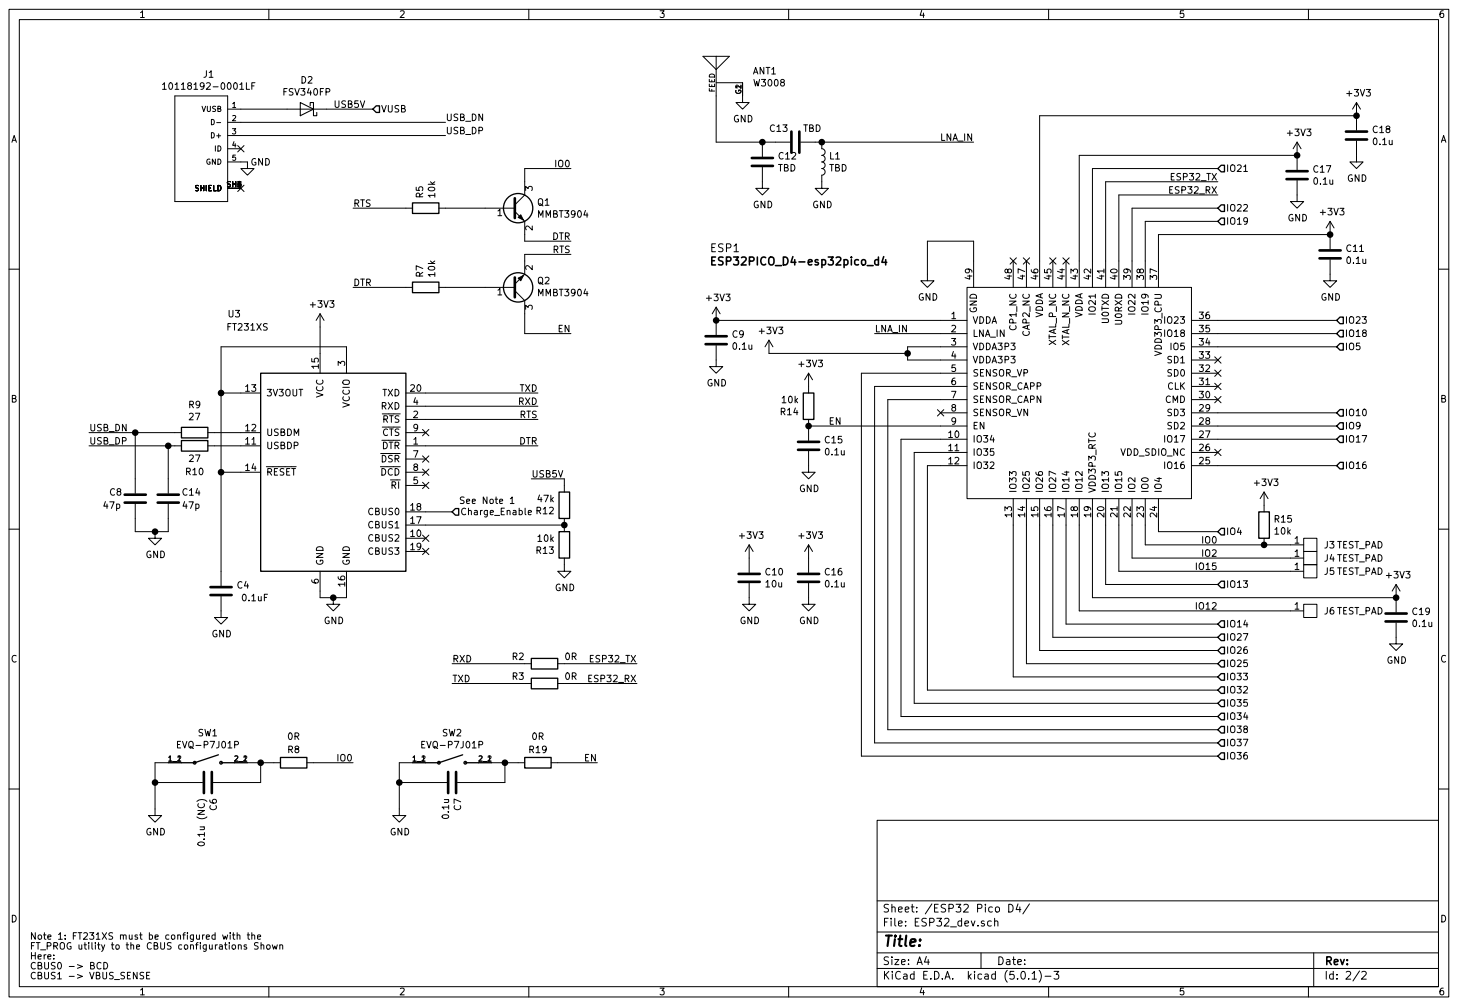
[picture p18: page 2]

IO37 See Note 1 Note 1: FT231XS must be configured with the

File: ESP32_dev.sch Sheet: /ESP32 Pico D4/
Id: 2/2 Title:

FT_PROG utility to the CBUS configurations Shown Here: CBUS0 -> BCD

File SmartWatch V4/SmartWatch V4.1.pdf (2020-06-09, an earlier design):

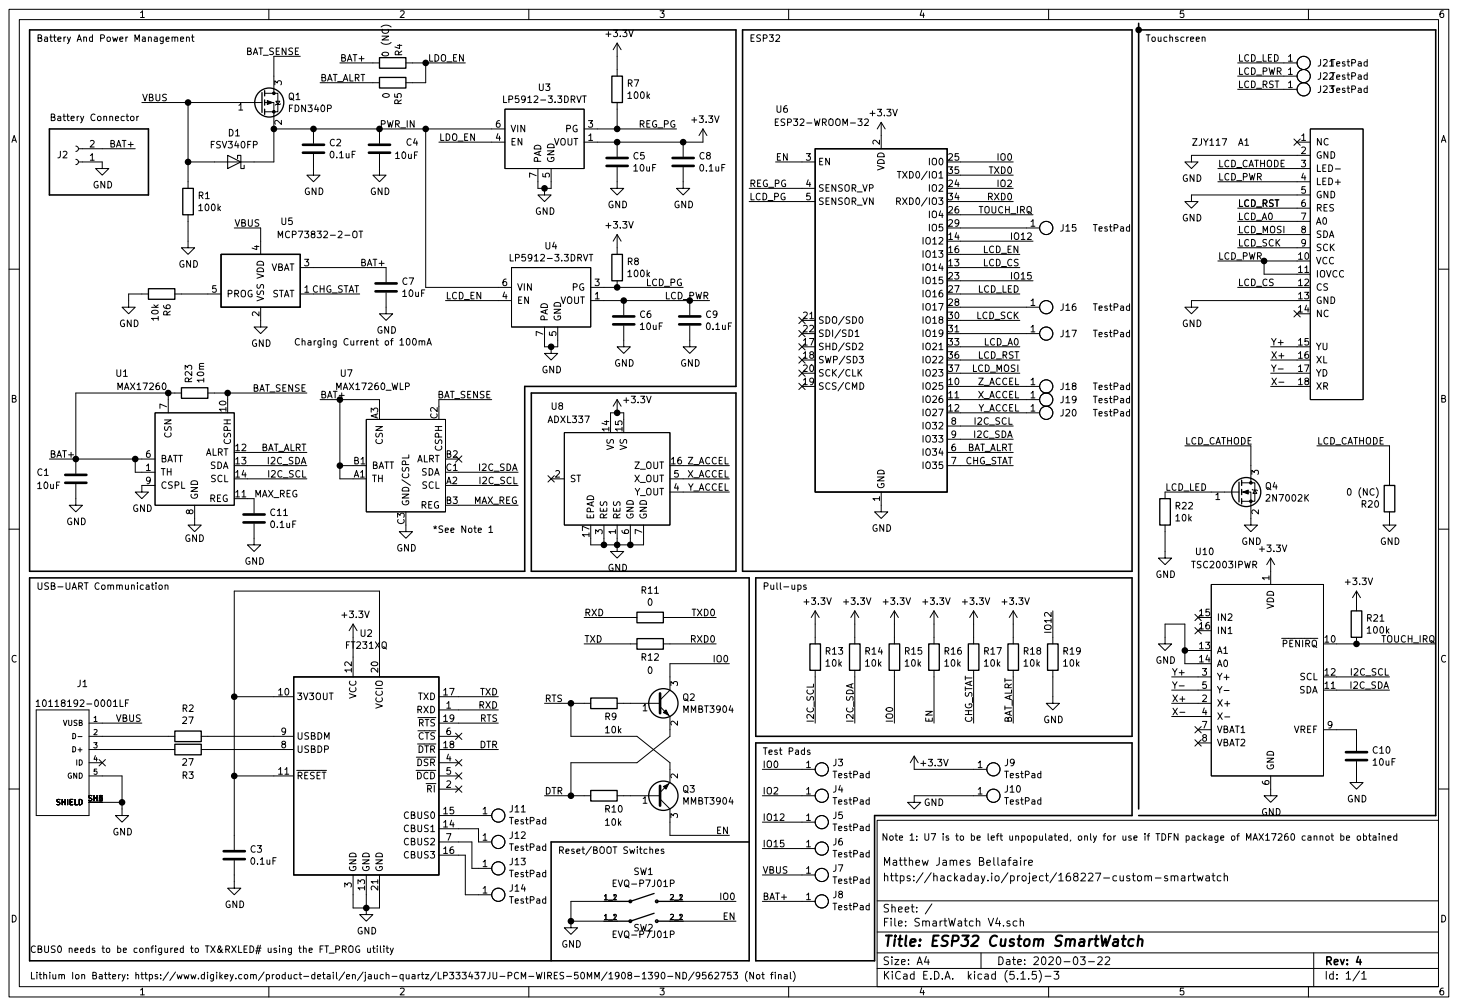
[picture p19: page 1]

Battery And Power Management

Touchscreen Charging Current of 100mA

2 SCK/CLK 20 SDO/SD0 21 SDI/SD1 22

8 CSPL 9 U1MAX17260 TH A1 SCL A2 CSN A3 BATT B1 ALRT B2 REG B3 SDA C1 CSPH C2 GND/CSPL C3 U7 MAX17260_WLP

1 VS 14 VS 15 Z_OUT 16 EPAD 17 ST 2 RES

3 DSR 4 DCD 5 CTS 6 CBUS2 7 USBDP 8 USBDM 9 U2 FT231XQ VDD

Id: 1/1 Title: ESP32 Custom SmartWatch

CBUS0 needs to be configured to TX&RXLED# using the FT_PROG utility

Lithium Ion Battery: https://www.digikey.com/product-detail/en/jauch-quartz/LP333437JU-PCM-WIRES-50MM/1908-1390-ND/9562753 (Not final)

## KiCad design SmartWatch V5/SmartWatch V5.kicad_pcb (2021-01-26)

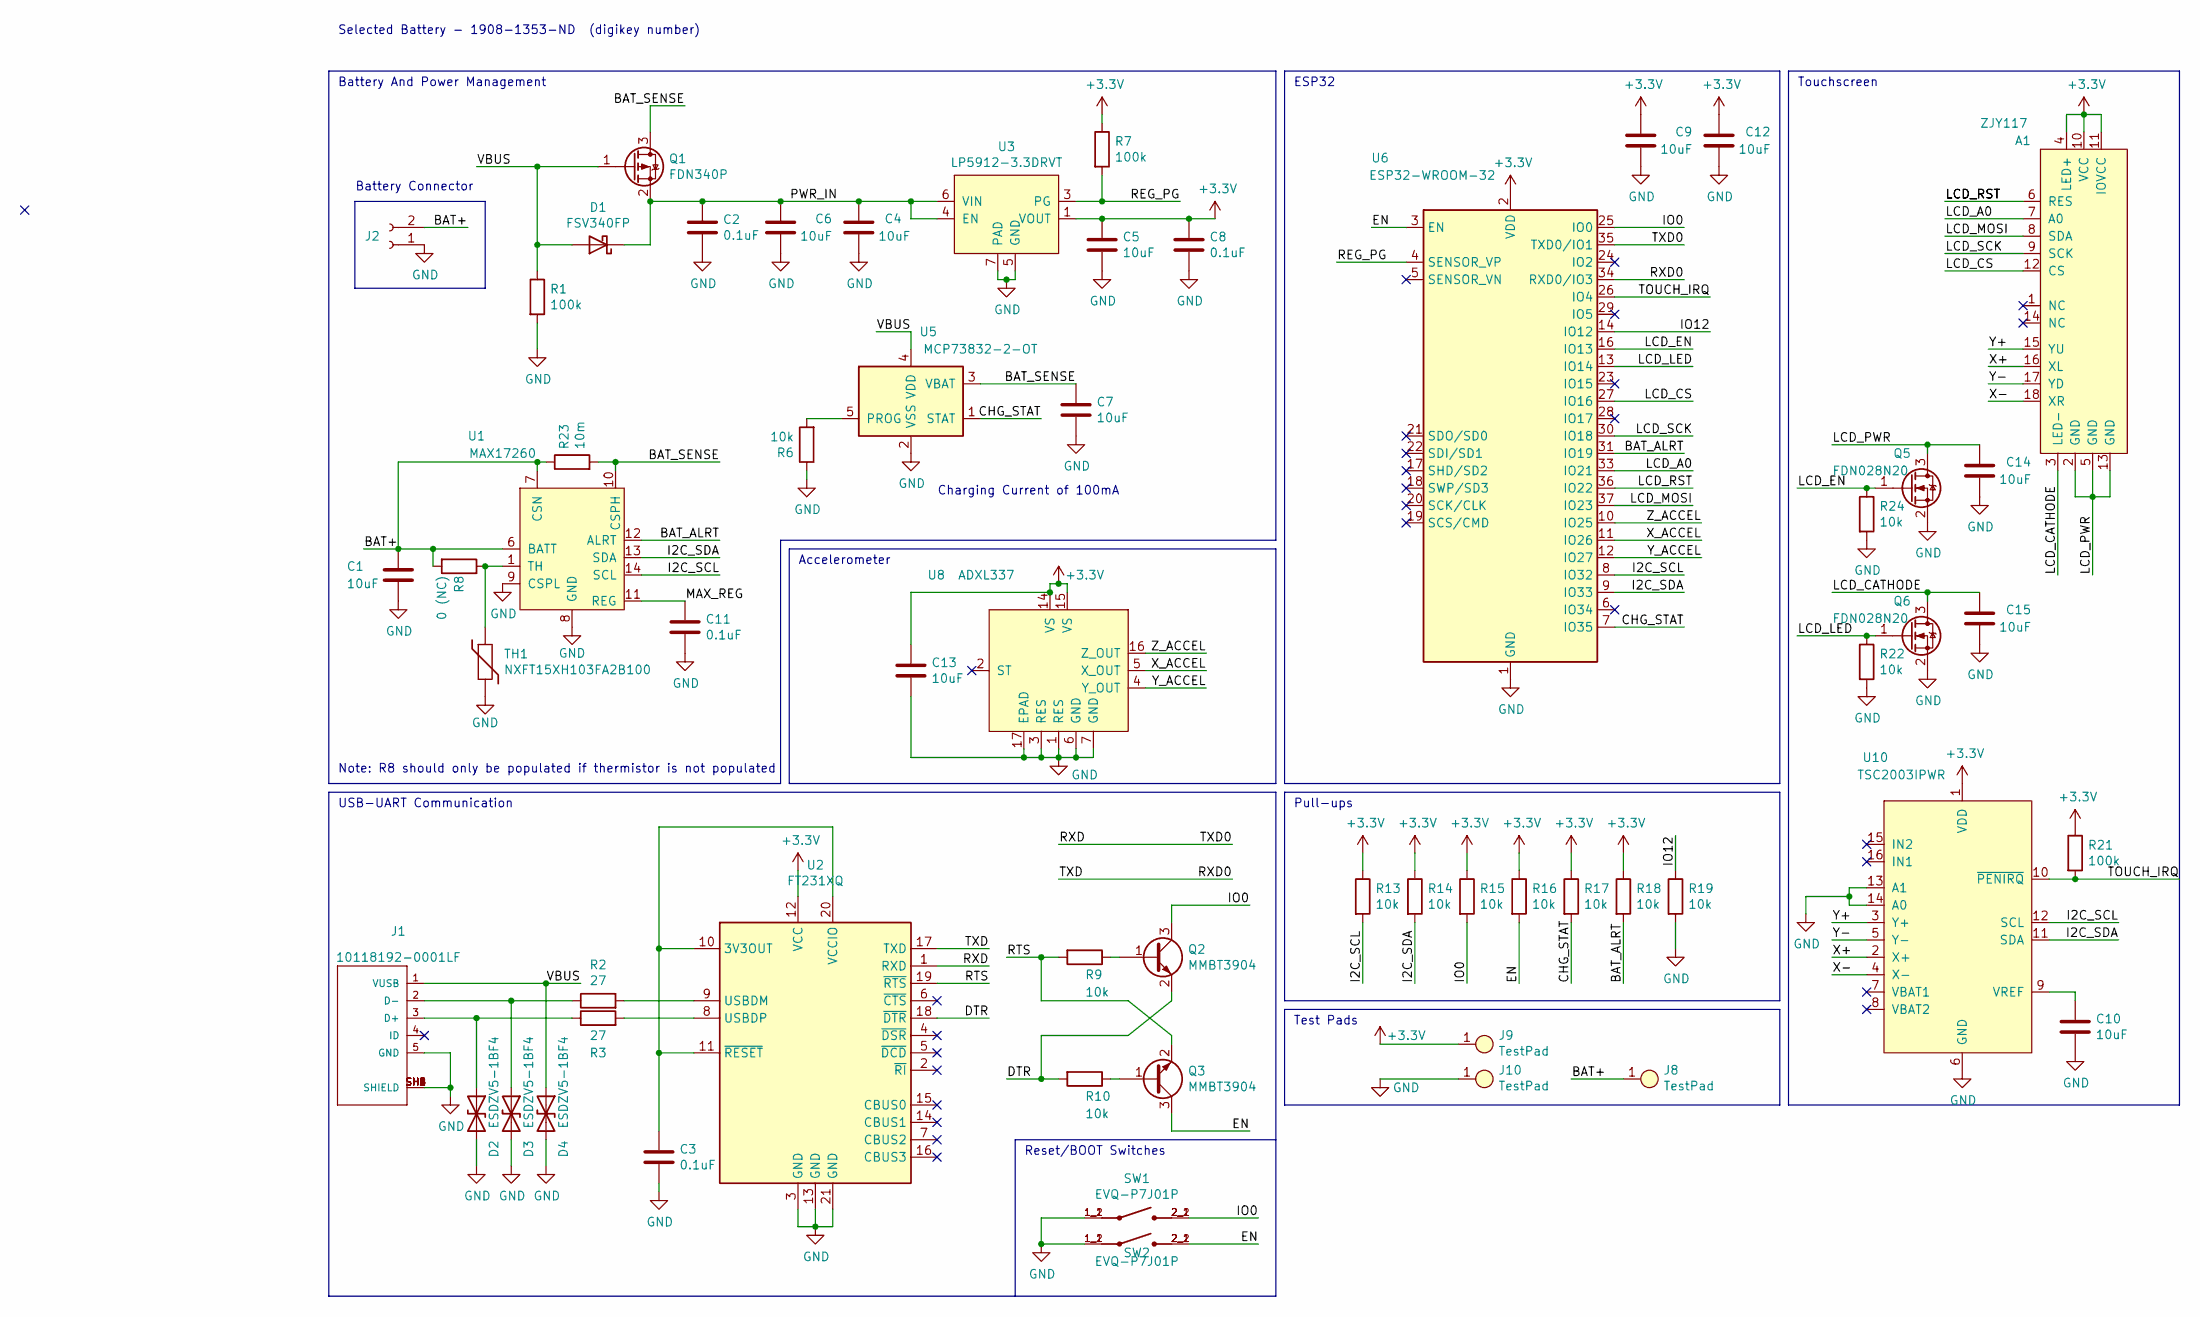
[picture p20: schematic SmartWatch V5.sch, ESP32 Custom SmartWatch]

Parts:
A1: ZJY117
C1, C4, C5, C6, C7, C9, C10, C12, C13, C14, C15: 10uF; C_0603_1608Metric; digikey 478-10766-1-ND
C2, C3, C8, C11: 0.1uF; C_0603_1608Metric; digikey 1276-1006-1-ND
D1: FSV340FP; D_SOD-123; digikey FSV340FPCT-ND
D2, D3, D4: ESDZV5-1BF4; D_0201_0603Metric; digikey 497-17318-1-ND
J1: 10118192-0001LF; AMPHENOL_10118192-0001LF; digikey 609-4613-1-ND
J2: BATTERY
J8, J9, J10: TestPad; TESTPAD
Q1: FDN340P; SOT-23; digikey FDN340PCT-ND
Q2, Q3: MMBT3904; SOT-23; digikey 1727-4044-1-ND
Q5, Q6: FDN028N20; SOT-23; digikey FDN028N20OSCT-ND
R1, R7, R21: 100k; R_0603_1608Metric; digikey CR0603-JW-104ELFCT-ND
R2, R3: 27; R_0603_1608Metric; digikey RMCF0603JT27R0CT-ND
R6, R9, R10, R13, R14, R15, R16, R17, R18, R19, R22, R24: 10k; R_0603_1608Metric; digikey 311-10.0KCRCT-ND
R8: 0 (NC); R_0603_1608Metric; digikey 311-0.0GRCT-ND
R23: 10m; R_0805_2012Metric; digikey RL12T.010JCT-ND
SW1, SW2: EVQ-P7J01P; SW_EVQ-P7J01P; digikey P16767CT-ND
TH1: NXFT15XH103FA2B100; PinHeader_1x02_P1.00mm_Vertical; digikey 490-5630-ND
U1: MAX17260; TDFN16-EP; digikey 175-MAX17260SEWL+TCT-ND
U2: FT231XQ; QFN-20-1EP_4x4mm_P0.5mm_EP2.5x2.5mm; digikey 768-1128-1-ND
U3: LP5912-3.3DRVT; WSON-6-1EP_2x2mm_P0.65mm_EP1x1.6mm_ThermalVias; digikey 296-44153-1-ND
U5: MCP73832-2-OT; SOT-23-5; digikey MCP73832T-2ACI/OTCT-ND
U6: ESP32-WROOM-32; digikey 1904-1010-1-ND
U8: ADXL337; ADXL337BCPZ-RL; digikey ADXL337BCPZ-RLCT-ND
U10: TSC2003IPWR; TSSOP-16_4.4x5mm_P0.65mm; digikey 296-14340-1-ND

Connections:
+3V3: A1.4 (LED+), A1.10 (VCC), A1.11 (IOVCC), C5.1, C8.1, C9.1, C12.1, C13.1, J9.1, R7.1, R13.1, R14.1, R15.1, R16.1, R17.1, R18.1, R21.1, U2.12 (VCC), U3.1 (VOUT), U6.2 (VDD), U8.14 (VS), U8.15 (VS), U10.1 (VDD)
/BAT+: C1.1, J2.2, J8.1, R8.2, R23.1, U1.6 (BATT), U1.7 (CSN)
/BAT_ALRT: R18.2, U1.12 (ALRT), U6.31 (IO19)
/BAT_SENSE: C7.1, Q1.3 (D), R23.2, U1.10 (CSPH), U5.3 (VBAT)
/CHG_STAT: R17.2, U5.1 (STAT), U6.7 (IO35)
/DTR: Q2.2 (E), R10.2, U2.18 (~DTR)
/EN: Q3.3 (C), R16.2, SW2.2_1 (2), SW2.2_2 (2), U6.3 (EN)
/I2C_SCL: R13.2, U1.14 (SCL), U6.8 (IO32), U10.12 (SCL)
/I2C_SDA: R14.2, U1.13 (SDA), U6.9 (IO33), U10.11 (SDA)
/IO0: Q2.3 (C), R15.2, SW1.2_1 (2), SW1.2_2 (2), U6.25 (IO0)
/IO12: R19.1, U6.14 (IO12)
/LCD_A0: A1.7 (A0), U6.33 (IO21)
/LCD_CATHODE: A1.3 (LED-), C15.1, Q6.3 (D)
/LCD_CS: A1.12 (CS), U6.27 (IO16)
/LCD_EN: Q5.1 (G), R24.1, U6.16 (IO13)
/LCD_LED: Q6.1 (G), R22.1, U6.13 (IO14)
/LCD_MOSI: A1.8 (SDA), U6.37 (IO23)
/LCD_PWR: A1.2 (GND), A1.5 (GND), A1.13 (GND), C14.1, Q5.3 (D)
/LCD_RST: A1.6 (RES), U6.36 (IO22)
/LCD_SCK: A1.9 (SCK), U6.30 (IO18)
/MAX_REG: C11.1, U1.11 (REG)
/PWR_IN: C2.1, C4.1, C6.1, D1.1 (K), Q1.2 (S), U3.4 (EN), U3.6 (VIN)
/REG_PG: R7.2, U3.3 (PG~), U6.4 (SENSOR_VP)
/RTS: Q3.2 (E), R9.2, U2.19 (~RTS)
/RXD: U2.1 (RXD), U6.35 (TXD0/IO1)
/RXD0: U2.17 (TXD), U6.34 (RXD0/IO3)
/TOUCH_IRQ: R21.2, U6.26 (IO4), U10.10 (~PENIRQ~)
/VBUS: D1.2 (A), D4.1 (A1), J1.1 (VUSB), Q1.1 (G), R1.1, U5.4 (VDD)
/X+: A1.16 (XL), U10.2 (X+)
/X-: A1.18 (XR), U10.4 (X-)
/X_ACCEL: U6.11 (IO26), U8.5 (X_OUT)
/Y+: A1.15 (YU), U10.3 (Y+)
/Y-: A1.17 (YD), U10.5 (Y-)
/Y_ACCEL: U6.12 (IO27), U8.4 (Y_OUT)
/Z_ACCEL: U6.10 (IO25), U8.16 (Z_OUT)
GND: C1.2, C2.2, C3.2, C4.2, C5.2, C6.2, C7.2, C8.2, C9.2, C10.2, C11.2, C12.2, C13.2, C14.2, C15.2, D2.2 (A2), D3.2 (A2), D4.2 (A2), J1.5 (GND), J1.SH1 (SHIELD), J1.SH2 (SHIELD), J1.SH3 (SHIELD), J1.SH4 (SHIELD), J1.SH5 (SHIELD), J1.SH6 (SHIELD), J2.1, J10.1, Q5.2 (S), Q6.2 (S), R1.2, R6.1, R19.2, R22.2, R24.2, SW1.1_1 (1), SW1.1_2 (1), SW2.1_1 (1), SW2.1_2 (1), TH1.2, U1.8 (GND), U1.9 (CSPL), U1.15 (EP), U2.3 (GND), U2.13 (GND), U2.21 (GND), U3.5 (GND), U3.7 (PAD), U5.2 (VSS), U6.1 (GND), U6.15 (GND), U6.38 (GND), U6.39 (GND), U8.1 (RES), U8.3 (RES), U8.6 (GND), U8.7 (GND), U8.17 (EPAD), U10.6 (GND), U10.13 (A1), U10.14 (A0)
unnamed: C3.1, U2.10 (3V3OUT), U2.11 (~RESET), U2.20 (VCCIO)
unnamed: C10.1, U10.9 (VREF)
unnamed: D2.1 (A1), J1.3 (D+), R3.1
unnamed: D3.1 (A1), J1.2 (D-), R2.1
unnamed: Q2.1 (B), R9.1
unnamed: Q3.1 (B), R10.1
unnamed: R2.2, U2.9 (USBDM)
unnamed: R3.2, U2.8 (USBDP)
unnamed: R6.2, U5.5 (PROG)
unnamed: R8.1, TH1.1, U1.1 (TH)

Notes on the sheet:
Pull-ups
Test Pads
Battery And Power Management
Battery Connector
Reset/BOOT Switches
ESP32
Touchscreen
USB-UART Communication
Charging Current of 100mA
Note: R8 should only be populated if thermistor is not populated
Selected Battery - 1908-1353-ND (digikey number)
Accelerometer

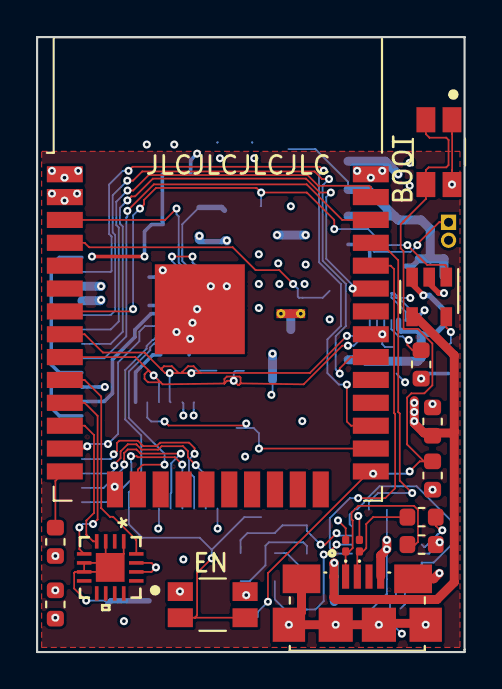
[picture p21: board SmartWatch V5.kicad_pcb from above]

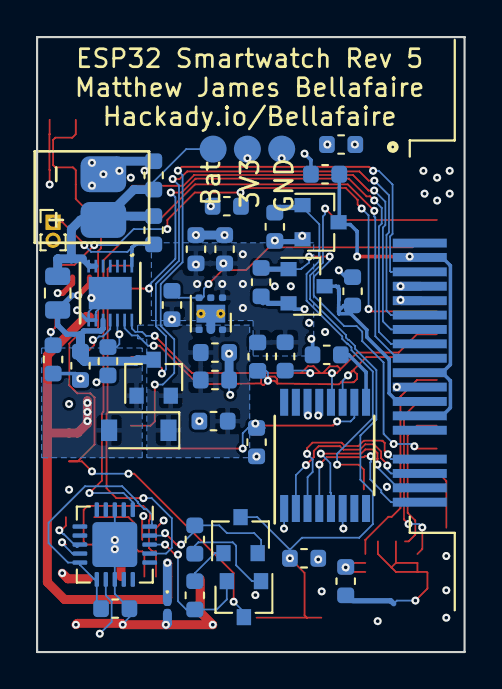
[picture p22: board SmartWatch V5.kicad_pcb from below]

Board: 4 copper layers, 23.7 x 34.2 mm, 59 parts (44 on the bottom side), 46 nets.

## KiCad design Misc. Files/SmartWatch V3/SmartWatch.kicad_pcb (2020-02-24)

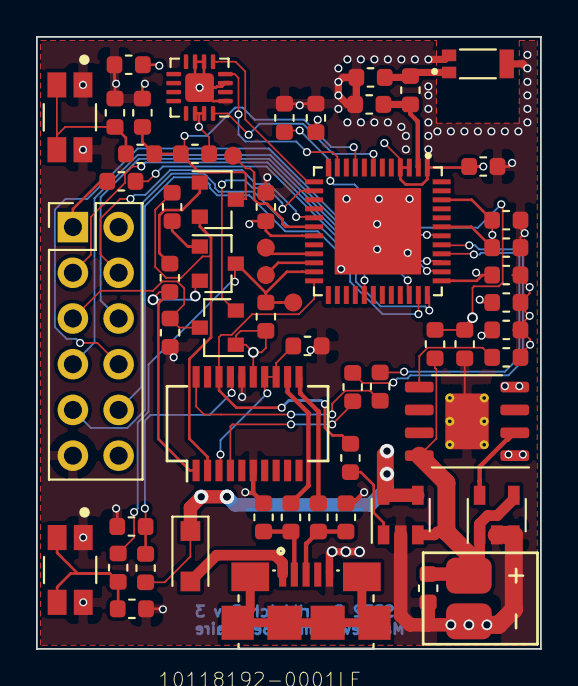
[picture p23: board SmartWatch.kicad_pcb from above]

Board: 4 copper layers, 28.0 x 34.0 mm, 58 parts (0 on the bottom side), 48 nets.

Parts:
ANT1: W3008; ANTENNA_W3008
C1, C2: 10nF; C_0603_1608Metric
C3, C20: 10uF; C_0603_1608Metric
C4: 0.1uF; C_0603_1608Metric
C5, C7, C9, C11, C15, C16, C17, C18, C19: 0.1u; C_0603_1608Metric
C6: 0.1u (NC); C_0603_1608Metric
C8, C14: 47p; C_0603_1608Metric
C10: 10u; C_0603_1608Metric
C12, C13: TBD; C_0603_1608Metric
D2: FSV340FP; D_SOD-123F
ESP1: ESP32PICO_D4-esp32pico_d4; ESP32_D4_PICO_HAND_SOLDER
J1: 10118192-0001LF; AMPHENOL_10118192-0001LF
J2: Bat_in; BATTERY
J3, J4, J5, J6: TEST_PAD
L1: TBD; L_0603_1608Metric
Q1, Q2: MMBT3904; SOT-23
Q3: FDN340P; SOT-23
R1, R2, R3, R4, R8, R19: 0R; R_0603_1608Metric
R5, R6, R7, R11, R13, R14, R15, R16: 10k; R_0603_1608Metric
R9, R10: 27; R_0603_1608Metric
R12: 47k; R_0603_1608Metric
SW1, SW2: EVQ-P7J01P; SW_EVQ-P7J01P
U1: S-13A1A33-E8T1U3; HSOP-8-1EP_3.9x4.9mm_P1.27mm_EP2.41x3.1mm_ThermalVias
U2: LCD_TOUCH; PinHeader_2x06_P2.54mm_Vertical
U3: FT231XS; SSOP-20_3.9x8.7mm_P0.635mm
U4: MAX9065; SOT-23-5
U5: MCP73811T-420I-OT; SOT-23-5
U7: ADXL337; LFCSP-16-1EP_3x3mm_P0.5mm_EP1.6x1.6mm

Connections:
+3V3: C2.1, C3.1, C9.1, C10.1, C11.1, C16.1, C17.1, C18.1, C19.1, ESP1.1, ESP1.3, ESP1.4, ESP1.19, ESP1.37, ESP1.43, ESP1.46, Q3.1, R14.2, R15.1, U1.1, U2.12, U3.15, U7.14, U7.15
/Charge_Enable: ESP1.24, R1.1, U3.18
/ESP32 Pico D4/DTR: Q1.2, R7.1, U3.1
/ESP32 Pico D4/EN: C15.1, ESP1.9, Q2.3, R14.1, R19.1
/ESP32 Pico D4/ESP32_RX: ESP1.40, R3.2
/ESP32 Pico D4/ESP32_TX: ESP1.41, R2.2
/ESP32 Pico D4/IO0: ESP1.23, J3.1, Q1.3, R8.1, R15.2
/ESP32 Pico D4/IO2: ESP1.22, J4.1
/ESP32 Pico D4/IO12: ESP1.18, J6.1
/ESP32 Pico D4/IO15: ESP1.21, J5.1
/ESP32 Pico D4/IO32: C5.1, ESP1.12, R6.1, R11.2
/ESP32 Pico D4/LNA_IN: C13.2, ESP1.2, L1.1
/ESP32 Pico D4/RTS: Q2.2, R5.1, U3.2
/ESP32 Pico D4/RXD: R2.1, U3.4
/ESP32 Pico D4/TXD: R3.1, U3.20
/ESP32 Pico D4/USB_DN: C8.1, J1.2, R9.1
/ESP32 Pico D4/USB_DP: C14.1, J1.3, R10.2
/LCD_A0: ESP1.42, U2.8
/LCD_CS: ESP1.34, U2.3
/LCD_LED: Q3.3, R16.2, U2.5
/LCD_LED_CTRL: ESP1.14, Q3.2
/LCD_PEN: ESP1.29, R4.2
/LCD_RST: ESP1.39, U2.7
/LCD_SCK: ESP1.35, U2.9
/MISO: ESP1.38, U2.6
/MOSI: ESP1.36, U2.10
/TOUCH_CS: ESP1.17, U2.4
BAT+: C20.1, J2.2, R6.2, U1.8, U4.1, U4.4, U5.3
GND: ANT1.G1, ANT1.G2, C1.2, C2.2, C3.2, C4.2, C5.2, C6.2, C7.2, C8.2, C9.2, C10.2, C11.2, C12.2, C14.2, C15.2, C16.2, C17.2, C18.2, C19.2, C20.2, ESP1.49, J1.5, J2.1, L1.2, R11.1, R13.1, R16.1, SW1.1_1, SW1.1_2, SW2.1_1, SW2.1_2, U1.4, U1.9, U2.11, U3.6, U3.16, U4.2, U4.3, U5.2, U7.1, U7.3, U7.6, U7.7, U7.17
unnamed: ANT1.FEED, C12.1, C13.1
unnamed: C1.1, U1.5
unnamed: C4.1, U3.3, U3.13, U3.14
unnamed: C6.1, R8.2, SW1.2_1, SW1.2_2
unnamed: C7.1, R19.2, SW2.2_1, SW2.2_2
unnamed: D2.2, J1.1
unnamed: J1.SH1, J1.SH2, J1.SH3, J1.SH4, J1.SH5, J1.SH6
unnamed: Q1.1, R5.2
unnamed: Q2.1, R7.2
unnamed: R1.2, U5.1
unnamed: R4.1, U2.1
unnamed: R9.2, U3.12
unnamed: R10.1, U3.11
unnamed: R12.1, R13.2, U3.17
UV_LO: U1.2, U4.5
VUSB: D2.1, R12.2, U5.4, U5.5
X_SIG: ESP1.13, U7.5
Y_SIG: ESP1.11, U7.4
Z_SIG: ESP1.7, U7.16

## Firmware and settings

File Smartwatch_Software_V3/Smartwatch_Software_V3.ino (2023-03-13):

/*****************************************************************************
  The MIT License (MIT)
  Copyright (c) 2020 Matthew James Bellafaire
  Permission is hereby granted, free of charge, to any person obtaining a copy
  of this software and associated documentation files (the "Software"), to deal
  in the Software without restriction, including without limitation the rights
  to use, copy, modify, merge, publish, distribute, sublicense, and/or sell
  copies of the Software, and to permit persons to whom the Software is
  furnished to do so, subject to the following conditions:
  The above copyright notice and this permission notice shall be included in all
  copies or substantial portions of the Software.
  THE SOFTWARE IS PROVIDED "AS IS", WITHOUT WARRANTY OF ANY KIND, EXPRESS OR
  IMPLIED, INCLUDING BUT NOT LIMITED TO THE WARRANTIES OF MERCHANTABILITY,
  FITNESS FOR A PARTICULAR PURPOSE AND NONINFRINGEMENT. IN NO EVENT SHALL THE
  AUTHORS OR COPYRIGHT HOLDERS BE LIABLE FOR ANY CLAIM, DAMAGES OR OTHER
  LIABILITY, WHETHER IN AN ACTION OF CONTRACT, TORT OR OTHERWISE, ARISING FROM,
  OUT OF OR IN CONNECTION WITH THE SOFTWARE OR THE USE OR OTHER DEALINGS IN THE
  SOFTWARE.
******************************************************************************/

#include "Declarations.h"
#include "drawable.h"

int batteryPercentage = 100;
esp_sleep_wakeup_cause_t wakeup_reason;
int wakeup_count = 0;
boolean timeUpdated = false;
boolean notificationsUpdated = false;
RTC_DATA_ATTR boolean deep_sleep_reset = false;

void onConnectEvent()
{
  updateTime();
}

void setup()
{
#ifdef DEBUG
  Serial.begin(115200);
  Serial.println("ESP32 Smartwatch");
#endif

  if (!SPIFFS.begin(true))
  {
    Serial.println("SPIFFS Mount Failed");
  }

  //for testing formatting is necessary
  // bool formatted = false;
  // formatted = SPIFFS.format();

  // if (formatted)
  // {
  //   Serial.println("\n\nSuccess formatting");
  // }
  // else
  // {
  //   Serial.println("\n\nError formatting");
  // }

  listDir(SPIFFS, "/", 0);

  EEPROM.begin(EEPROM_SIZE);
  Wire.begin(I2C_SDA, I2C_SCL, 400000);
  pinMode(CHG_STAT, INPUT);
  initLCD(false);
  initBatMonitor();
  initTouch();

  initBLE();

  printDebug("Starting Advertisement");
  startBLEAdvertising();

  //manually setting daylight savings until we get a settings menu on V3
  //  setDataField(0, "daylight_sav");

  loadEEPROMSettings();

  // create "watchdog task" to put the device in deepsleep if something goes wrong
  // xTaskCreatePinnedToCore(watchDog, "watchdog", 1024, NULL, 3, NULL, 0);
  if (CLEAR_TOUCH_CALIBRATION)
    setCalibrationPage();
  else
    setHomePage();
  // updateTime();
}

void getNotifications()
{
  boolean success = sendBLE("/notifications", &notificationData, false);
  if (success)
  {
    notificationsUpdated = true;
    printDebug("notifications updating");
  }
}

unsigned long currentWakeLock = 0;
// allows things to request the screen to be kept on for a certain number of milliseconds
// if multiple things are requesting wakelock the longest wakelock will be kept.
void requestWakeLock(int milliseconds)
{
  unsigned long newWakelock = milliseconds + millis();
  if (newWakelock > currentWakeLock)
    currentWakeLock = newWakelock;
}

boolean wakeupCheck()
{
  return ((millis() - lastTouchTime) < 3000) || (readZAccel() > ACCELEROMETER_STAY_AWAKE_THRESHOLD) || (millis() < currentWakeLock) && !deep_sleep_reset;
}

void deviceSleep()
{
  deep_sleep_reset = false;
  batteryPercentage = getBatteryPercentage();
  digitalWrite(LCD_LED, LOW);
  // re-enable touch wakeup

  deinitBLE();

  printDebug("Going to sleep");

  Serial.flush();

  // put display to sleep
  tft.enableSleep(true);

  deactivateTouch();

  connected = false;
  if (wakeup_count > 4)
  {
    esp_sleep_enable_ext0_wakeup(GPIO_NUM_4, 0); // 1 = High, 0 = Low
    esp_sleep_enable_timer_wakeup(10);
    deep_sleep_reset = true;
    esp_deep_sleep_start();
  }
  else
  {
    esp_sleep_enable_ext0_wakeup(GPIO_NUM_4, 0); // 1 = High, 0 = Low
    esp_light_sleep_start();
  }
}

void onWakeup()
{
  wakeup_count++;

  getRTCTime();
  setHomePage();

  // wake up display
  tft.enableSleep(false);
  digitalWrite(LCD_LED, HIGH);

  // new wakeup so we'll want to update notifications next chance we get
  notificationsUpdated = false;
  timeUpdated = false;

  activateTouch();

  initBLE();
  printDebug("Starting Advertisement");

  printDebug("This is wakeup: " + String(wakeup_count));
  // startBLEAdvertising();
}

void loop()
{
  while (wakeupCheck())
  {
    drawFrame();

    if (connected)
    {
      if (!notificationsUpdated)
        getNotifications();
    }
  }

  deviceSleep();

  // the program halts until this point so we know that there was a touch
  // if this line is being executed since the ESP32 has been woken up.
  onWakeup();
}

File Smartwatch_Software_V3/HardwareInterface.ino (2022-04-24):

/*****************************************************************************
  The MIT License (MIT)
  Copyright (c) 2020 Matthew James Bellafaire
  Permission is hereby granted, free of charge, to any person obtaining a copy
  of this software and associated documentation files (the "Software"), to deal
  in the Software without restriction, including without limitation the rights
  to use, copy, modify, merge, publish, distribute, sublicense, and/or sell
  copies of the Software, and to permit persons to whom the Software is
  furnished to do so, subject to the following conditions:
  The above copyright notice and this permission notice shall be included in all
  copies or substantial portions of the Software.
  THE SOFTWARE IS PROVIDED "AS IS", WITHOUT WARRANTY OF ANY KIND, EXPRESS OR
  IMPLIED, INCLUDING BUT NOT LIMITED TO THE WARRANTIES OF MERCHANTABILITY,
  FITNESS FOR A PARTICULAR PURPOSE AND NONINFRINGEMENT. IN NO EVENT SHALL THE
  AUTHORS OR COPYRIGHT HOLDERS BE LIABLE FOR ANY CLAIM, DAMAGES OR OTHER
  LIABILITY, WHETHER IN AN ACTION OF CONTRACT, TORT OR OTHERWISE, ARISING FROM,
  OUT OF OR IN CONNECTION WITH THE SOFTWARE OR THE USE OR OTHER DEALINGS IN THE
  SOFTWARE.
******************************************************************************/
/* Hardware interfacing code, this should ideally be the only file that requires modification if
    the hardware should change, everything else is more-or-less talking to a function in this file
    if any hardware external to the ESP32 needs to talk
*/

/********************************************************************
                                LCD
 ********************************************************************/
void initLCD(boolean backlight_on)
{
  pinMode(LCD_EN, OUTPUT);
  digitalWrite(LCD_EN, HIGH);
  tft.initR(INITR_GREENTAB); // initialize a ST7735S chip, green tab
  tft.setRotation(3);
  tft.fillScreen(BACKGROUND_COLOR);
  pinMode(LCD_LED, OUTPUT);
  digitalWrite(LCD_LED, backlight_on);

  // ledcSetup(LCD_BACKLIGHT_PWM_CHAN, 300, 8);
  // ledcAttachPin(LCD_LED, LCD_BACKLIGHT_PWM_CHAN);
}

// this really only exists for readability elsewhere in the code.
void setBacklight(byte brightness)
{
  ledcWrite(LCD_BACKLIGHT_PWM_CHAN, brightness);
}

/********************************************************************
                               Touch
 ********************************************************************/
int rapidTouchCount = 0;

// watchdog tasks, it's possible some of the code can bind up. This at least prevents
// the user from having to manually press the reset button
void watchDog(void *pvParameters)
{
  (void)pvParameters;

  for (;;)
  {
    //    printDebug("***watchdog serviced***");
    if (wakeup_reason == ESP_SLEEP_WAKEUP_EXT0)
    {
      if (millis() > lastTouchTime + 20000 && readZAccel() < ACCELEROMETER_STAY_AWAKE_THRESHOLD)
      {
        esp_sleep_enable_timer_wakeup(1);
        esp_deep_sleep_start();
      }
    }
    vTaskDelay(500);
  }
}

/* Touch interrupt
   This interrupt triggers the touch handling task defined in TouchInterface.ino which allows
   for touch areas to be identified. It also contains a rapid-touch shutdown which can be triggerred
   by tapping the screen rapidly.
*/
void IRAM_ATTR TOUCH_ISR()
{
  //  printDebug("TouchInterrupt");
  if ((millis() - lastTouchTime < 200))
  {
    if ((millis() - lastTouchTime > 50))
      rapidTouchCount++;
    // printDebug(String(rapidTouchCount)); //this line causes crashes occasionally leave it out unless specifically working on this function (and of course expect some crashes)
    if (rapidTouchCount > 50)
    {
#ifdef DEBUG
      Serial.println("**** Rapid Touch shutdown registered ****");
      Serial.flush();
#endif

      // clear calibration data after rapid touch
      CLEAR_TOUCH_CALIBRATION = true;
      rapidTouchCount = 0;
      // rapid touch is meant to restart, using deep sleep we can essentially go back to
      // the same state we would get from a cold restart
      esp_sleep_enable_timer_wakeup(1);
      esp_deep_sleep_start();
    }
  }
  else
  {
    rapidTouchCount = 0;
  }
#ifdef USE_TOUCH_HANDLING_TASK
  xTaskCreatePinnedToCore(TouchTask, "TOUCH_TASK", 4 * 1024, (void *)1, 2, NULL, 1);
#endif
  lastTouchTime = millis();
}

// init touch IC
void initTouch()
{

  // dummy read the touch controller, bits 2 and 3 determine the power down state, 00 enables touch IRQ and puts the device into power down
  struct point p;
  p.x = readRegister(TOUCH_ADDR, 0b11010010);
  p.y = readRegister(TOUCH_ADDR, 0b11000010);

  pinMode(TOUCH_IRQ, INPUT);

  rapidTouchCount = 0;
  attachInterrupt(TOUCH_IRQ, TOUCH_ISR, FALLING);
}

// activates touch interrupt
void activateTouch()
{
  attachInterrupt(TOUCH_IRQ, TOUCH_ISR, FALLING);
}

// deactivates touch interrupt
void deactivateTouch()
{
  detachInterrupt(TOUCH_IRQ);
  rapidTouchCount = 0;
}
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

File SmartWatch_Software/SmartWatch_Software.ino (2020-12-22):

/*****************************************************************************
  The MIT License (MIT)

  Copyright (c) 2020 Matthew James Bellafaire

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
  THE SOFTWARE IS PROVIDED "AS IS", WITHOUT WARRANTY OF ANY KIND, EXPRESS OR
  IMPLIED, INCLUDING BUT NOT LIMITED TO THE WARRANTIES OF MERCHANTABILITY,
  FITNESS FOR A PARTICULAR PURPOSE AND NONINFRINGEMENT. IN NO EVENT SHALL THE
  AUTHORS OR COPYRIGHT HOLDERS BE LIABLE FOR ANY CLAIM, DAMAGES OR OTHER
  LIABILITY, WHETHER IN AN ACTION OF CONTRACT, TORT OR OTHERWISE, ARISING FROM,
  OUT OF OR IN CONNECTION WITH THE SOFTWARE OR THE USE OR OTHER DEALINGS IN THE
  SOFTWARE.
******************************************************************************/

#include "Declarations.h"

#define uS_TO_S_FACTOR 1000000ULL /* Conversion factor for micro seconds to seconds */
#define TIME_TO_SLEEP 60         /* Time ESP32 will go to sleep (in seconds) */

RTC_DATA_ATTR int bootCount = 0;
RTC_DATA_ATTR boolean YWakeupCondition = false;
RTC_DATA_ATTR int YWakeupCount = 0;

static void RTC_IRAM_ATTR wake_stub();

static void RTC_IRAM_ATTR wake_stub() {

}

//puts device to sleep and configures wakeup sources
void deviceSleep() {
  //re-enable touch wakeup
  esp_sleep_enable_ext0_wakeup(GPIO_NUM_4, 0); //1 = High, 0 = Low
  esp_set_deep_sleep_wake_stub(&wake_stub);
  esp_deep_sleep_start();
}

void setup()
{
  unsigned long wakeupTime = micros();
  unsigned long chrono = micros();
#ifdef DEBUG
  Serial.begin(115200);
#endif
  printDebug("bootCount = " + String(bootCount));

  //init I2C communication
  Wire.begin(I2C_SDA, I2C_SCL, 100000);

  esp_sleep_wakeup_cause_t wakeup_reason;
  wakeup_reason = esp_sleep_get_wakeup_cause();

  pinMode(CHG_STAT, INPUT);
  pinMode(TOUCH_IRQ, INPUT);
  initTouch();

  EEPROM.begin(EEPROM_SIZE);

  if (getBatteryVoltage() < 3.2) {

    printDebug("Battery Voltage is too low to start device: " + String(getBatteryVoltage(), 3));
    pinMode(LCD_LED, OUTPUT);
    pinMode(LCD_EN, OUTPUT);
    digitalWrite(LCD_EN, HIGH);

    for (int a = 0; a < 3; a++) {
      digitalWrite(LCD_LED, HIGH);
      delay(100);
      digitalWrite(LCD_LED, LOW);
      delay(100);
    }



  } else {

    //the battery monitor only needs to be configured once when powered on.
    if (bootCount == 0)
    {
      notificationData[0] = 0;
      initTouch();
      initLCD();
      initBatMonitor();
      testScreen();
      tft.println("phone notifications obtained");
      //      getInternetTime();
      updateTimeFromNotificationData();
      tft.println("obtained time");

      printDebug("Battery Monitor initialized");

    }

    //Check if this is the first reboot and get ready to setup another sleep
    ++bootCount;

    switch (wakeup_reason)
    {
      case ESP_SLEEP_WAKEUP_EXT0:
        deviceActive = true;
        //if woken up by user touching screen
        initTouch();
        initLCD();
        MainLoop();
        break;
      case ESP_SLEEP_WAKEUP_EXT1:
        break;
      case ESP_SLEEP_WAKEUP_TIMER:
        break;
      default:
        printDebug("Wakeup was not caused by deep sleep: " + wakeup_reason);
        break;
    }
  }

  printDebug("Going to sleep now");

#ifdef DEBUG
  printDebug("Awake for " + String(micros() - wakeupTime) + "uS");
  Serial.flush();
#endif

  deviceSleep();
}

void loop()
{
}

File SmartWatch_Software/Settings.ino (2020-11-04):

/*****************************************************************************
  The MIT License (MIT)

  Copyright (c) 2020 Matthew James Bellafaire

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
  THE SOFTWARE IS PROVIDED "AS IS", WITHOUT WARRANTY OF ANY KIND, EXPRESS OR
  IMPLIED, INCLUDING BUT NOT LIMITED TO THE WARRANTIES OF MERCHANTABILITY,
  FITNESS FOR A PARTICULAR PURPOSE AND NONINFRINGEMENT. IN NO EVENT SHALL THE
  AUTHORS OR COPYRIGHT HOLDERS BE LIABLE FOR ANY CLAIM, DAMAGES OR OTHER
  LIABILITY, WHETHER IN AN ACTION OF CONTRACT, TORT OR OTHERWISE, ARISING FROM,
  OUT OF OR IN CONNECTION WITH THE SOFTWARE OR THE USE OR OTHER DEALINGS IN THE
  SOFTWARE.
******************************************************************************/
#define settingNumber 3
#define MAX_ON_SCREEN_SETTINGS_BUTTONS 5

#define SETTING_BUTTON_WIDTH 128
#define SETTING_BUTTON_HEIGHT 25

int settingScrollPosition = 0;
#define SETTING_OPTIONS 8

//define options positions
#define CONFIGURE_SETTINGS 0
#define REUPDATE_TIME 1
#define BATTERY 2
#define ACCELTEST 3
#define NETWORK_SELECT 4
#define OBTAIN_NOTIFICATIONS 5
#define VIEW_RAW_NOTIFICATIONS 6
#define ABOUT 7

button settingButtons[SETTING_OPTIONS] = {
  {0, 0, SETTING_BUTTON_WIDTH, SETTING_BUTTON_HEIGHT, INTERFACE_COLOR, BACKGROUND_COLOR, "Configure Settings"},
  {0, 0, SETTING_BUTTON_WIDTH, SETTING_BUTTON_HEIGHT, INTERFACE_COLOR, BACKGROUND_COLOR, "Re-update Time"},
  {0, 0, SETTING_BUTTON_WIDTH, SETTING_BUTTON_HEIGHT, INTERFACE_COLOR, BACKGROUND_COLOR, "Battery Stats"},
  {0, 0, SETTING_BUTTON_WIDTH, SETTING_BUTTON_HEIGHT, INTERFACE_COLOR, BACKGROUND_COLOR, "AccelTest"},
  {0, 0, SETTING_BUTTON_WIDTH, SETTING_BUTTON_HEIGHT, INTERFACE_COLOR, BACKGROUND_COLOR, "Select Network"},
  {0, 0, SETTING_BUTTON_WIDTH, SETTING_BUTTON_HEIGHT, INTERFACE_COLOR, BACKGROUND_COLOR, "Obtain Notifications"},
  {0, 0, SETTING_BUTTON_WIDTH, SETTING_BUTTON_HEIGHT, INTERFACE_COLOR, BACKGROUND_COLOR, "Raw Notifications"},
  {0, 0, SETTING_BUTTON_WIDTH, SETTING_BUTTON_HEIGHT, INTERFACE_COLOR, BACKGROUND_COLOR, "About"}
};

//String settingOptions[] = {
//  "Re-update Time",
//  "About"
//};

void settingsLoop()
{
  //settings has a seperate timeout
  while (currentPage == SETTINGS)
  {
    handleTouch();
    delay(10);
  }
}

//not currently working
void changeNetwork()
{
  SelectionWindow w = SelectionWindow(0, 14, 160, 100);

  int networks[networkNumber];

  for (int a = 0; a < networkNumber; a++)  {
    w.addOption(ssidList[a]);
  }

  printDebug("Focusing network selection window");

  delay(50); //in some cases the touch can get read twice and exit the selection screen right away, this delay prevents it

  int selectedOption = w.focus() - 1; //the cancel option of the selection counts as option 0, since array is zero indexed we subtract

  printDebug("network selection window lost focus with selected option: " + String(selectedOption));

  if (selectedOption >= 0)  {
    ssid = ssidList[selectedOption];
    password = passwordList[selectedOption];
    testWifi();
  }
  else  {

    delay(100);
    printDebug("user exited selection window with cancel button");
  }
}

void drawSettings()
{
  //  frameBuffer -> fillScreen(BACKGROUND_COLOR);
  frameBuffer -> drawRGBBitmap(0, 0, background, SCREEN_WIDTH, SCREEN_HEIGHT);
  //configuring buttons
  if (SETTING_OPTIONS > MAX_ON_SCREEN_SETTINGS_BUTTONS)
  {
    for (int a = 0; a < MAX_ON_SCREEN_SETTINGS_BUTTONS; a++)
    {
      settingButtons[a + settingScrollPosition]._x = 1;
      settingButtons[a + settingScrollPosition]._y = 1 + SETTING_BUTTON_HEIGHT * a;
      paintButton(settingButtons[a + settingScrollPosition]);
    }
  }
  else
  {
    for (int a = 0; a < SETTING_OPTIONS; a++)
    {
      settingButtons[a]._x = 1;
      settingButtons[a]._y = 1 + SETTING_BUTTON_HEIGHT * a;
      paintButton(settingButtons[a]);
    }
  }
  paintButtonFull(upArrowButton);
  paintButtonFull(downArrowButton);

  paintButton(homeButton);

  tft.drawRGBBitmap (0, 0, frameBuffer -> getBuffer (), SCREEN_WIDTH, SCREEN_HEIGHT);
}
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

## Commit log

2020-02-24 First Commit of V1 Files
    [ESP32 PICO.sch, ESP32_dev.sch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]
2020-02-24 Commit of V2 Files
    [ESP32 PICO.sch, ESP32_dev.sch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]
2020-02-24 Commit of Rev3 Board files
    (Currently Working Board)
    [ESP32 PICO.sch, ESP32_dev.sch, SmartWatch (Just important components).csv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]
2020-02-24 Created new design for 3D printed case
    [Rev 3.1 Body.stl, Rev 3.1 Top.stl]
2020-02-25 Implemented code to turn screen backlight on or off
    [3.1 body.stl, 3.1 top.stl, Rev 3.1 Body.stl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]
2020-02-26 Designed Version 3.2 Case
    [3.2 Body.stl, 3.2 Top.stl]
2020-02-26 added holes to 3.2 case to prevent BOOT and EN buttons from being pressed
    [3.2 Body.stl, 3.2 Top.stl]
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2020-03-10 added a "bodge" to fix the time display for a little while
    [Declarations.h, SmartWatch_Software.ino]
2020-03-11 Added notes to schematic for rev 4 changes
    [SmartWatch.sch]
2020-03-11 minor comment additions to code and schematic
    [SmartWatch.sch]
2020-03-11 Comment additions to schematic
    [SmartWatch.sch]
2020-03-14 comment addition to schematic
    [SmartWatch.sch]
2020-03-22 Began work on REV4 Board
    [SmartWatch V4.kicad_pcb, SmartWatch V4.sch, SmartWatch.sch]
2020-03-23 Connected LCD and LCD power source
    [SmartWatch V4.sch]
2020-03-23 Completed Implementation of Touch Screen
    TODO: Final checks on circuit design
    [SmartWatch V4.sch]
2020-03-24 minor edits
    [SmartWatch V4.sch]
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2020-04-08 assigned all footprints to components
    [SmartWatch V4.sch]
2020-05-04 Completed work of schematic and board layout of revision 4
    Also began work on new body for the watch
    [4.1 bottom.stl, 4.1 top.stl, SmartWatch V4.kicad_pcb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]
2020-05-04 Switched to MAX17260 due to availability
    [3.1 body.stl, 3.1 top.stl, 3.2 Body.stl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]
2020-05-11 Changes to version 4 before sending off to production
    [4.1 bottom.stl, 4.1 top.stl, Power analysis of ESP32 Smartwatch.xlsx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]
2020-05-20 Added images of assembeld Revision 4 and did some work on the CAD drawing of the case. Started new software...
    (so yeah, little of everything)
    [SmartWatch V4.kicad_pcb]
2020-05-29 Edits to Rev 4 board
    [SmartWatch V4.kicad_pcb, SmartWatch V4.sch]
2020-06-05 Finished design of Rev 4.1 board and ordered
    - Also created an I2C device test program to aid assembly and future code
    [SmartWatch V4 BOM.csv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]
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2020-06-15 Started work on software for the project. Basic communication with I2C devices and driving the touch screen
    [SmartWatch V4.kicad_pcb, SmartWatch V4.sch]
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2020-06-15 Implemented settings menu ported from V3
    And changed kiCad schematic to reflect the changes made to the board to resolve charging issue
    [SmartWatch V4.sch]
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2020-06-29 Smartwatch will no longer start up when battery is below 3.2 volts
    [Battery_Monitor.ino, Home.ino, SmartWatch_Software.ino]
2020-06-29 Fixed bluetooth causing crash and made ALL notifications appear on smartwatch
    [BluetoothRecieve.ino, Declarations.h, Home.ino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]
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2020-06-30 Fixed issue causing a delay on startup when drawing the home menu
    also changed background image
    [Declarations.h, Home.ino, TimeTracker.ino]
2020-07-01 Renamed the defined parameters of the circular animation to prevent future issues
    [CircularAnimation.ino]
2020-07-01 fixed bug in displaying notifications where fields would display as "," when empty
    [Notifications.ino]
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2020-07-14 More fix-ups for the smartwatch when receiving BLE communications. Should resolve "lockup" issue created in last commit
    [BluetoothRecieve.ino, Declarations.h, Settings.ino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]
2020-07-14 fixed lockup when obtaining notifications
    [BluetoothRecieve.ino, SmartWatch_Software.ino]
2020-07-14 Fixed crashes due to null device in BluetoothRecieve.ino
    [BluetoothRecieve.ino]
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2020-07-15 Fixed a bug where the first notification in the list would not appear on the smartwatch
    [Home.ino, Notifications.ino]
2020-07-15 Fixed notification display bug on home screen
    [Notifications.ino]
2020-07-15 Fixed issue in notification display where notifications would be read only as ";" when they were actually null
    [Notifications.ino]
2020-07-15 notification screen on smartwatch should no longer start without selecting a notification
    [Notifications.ino]
2020-07-16 Fixed an issue where text would overflow scroll window
    [Window.ino]
2020-07-19 changed selection window to prevent user double tapping options
    [SelectionWindow.ino]
2020-07-20 Current time is now obtained directly from android companion app, this prevents RTC drift from being an issue
    [Declarations.h, Settings.ino, SmartWatch_Software.ino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]
2020-07-20 smartwatch should no longer update time from notification if data is old
    [Settings.ino, SmartWatch_Software.ino]
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2020-07-21 Fixed a bug where time would update from old notification data when updates were forced through the settings menu
    [Settings.ino]
2020-07-28 Rework of BLE code to speed up constant connections and allow future mediaplayer work
    [BluetoothRecieve.ino, Declarations.h, SmartWatch_Software.ino]
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2020-07-28 Song title should no longer cover the apps button
    [Apps.ino, Home.ino]
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2020-07-28 Moved bluetooth scanning and music related items to core 1 for stability and temporarily commented out app selection
    [Apps.ino, BluetoothRecieve.ino, Home.ino]
2020-07-29 Fixed BLE related crash
    [BluetoothRecieve.ino, Home.ino]
2020-07-29 Song title will now scroll across the bottom when it's too long
    [BluetoothRecieve.ino, Home.ino]
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2020-07-29 Bluetooth search is kept in separate thread but connecting has moved to main thread to prevent i2c conflicts
    [BluetoothRecieve.ino]
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2020-07-29 connectToSever should now only trigger when the correct device is found
    [Home.ino]
2020-08-02 Fixed a bug where smartwatch would lock up when forming connection in some cases
    [BluetoothRecieve.ino]
2020-08-03 Fixed crash caused by android device disconnecting at a specific time in the connection process
    [BluetoothRecieve.ino, Home.ino]
2020-08-03 Began Hardware redesign for revision 5
    - Edited LCD schematic symbol
    - removed secondary LDO
    - changed LCD over to being switched by n channel mosfet
    - Accelerometer can now be selectively switched on
    [SmartWatch V4-B_Cu.gbr, SmartWatch V4-B_Mask.gbr, SmartWatch V4-B_Paste.gbr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]
2020-08-03 Switched LCD_EN with LCD_CS so LCD can remain active using RTC pullup
    [SmartWatch V5.sch]
2020-08-03 Removed testpads that are no longer needed
    [SmartWatch V5.sch]
2020-08-03 Added Optional Thermistor for battery monitor
    [SmartWatch V5.sch]
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2020-08-03 Added datasheet for 2n7002K
    [SmartWatch V5.sch]
2020-08-03 Switched 2N7002K with FDN028N20 which has a significantly lower RDSon
    [SmartWatch V5.sch]
2020-08-03 Added Surge/ESD protection to USB port
    [SmartWatch V5.sch]
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2020-08-03 Added footprint for Thermistor
    [SmartWatch V5.sch]
2020-08-03 Began 4 Layer Layout
    [SmartWatch V5.kicad_pcb, SmartWatch V5.sch]
2020-08-03 Removed 0 ohm jumpers on UART connection
    [SmartWatch V5.sch]
2020-08-03 Connected ACCEL_EN to ESP32
    [SmartWatch V5.sch]
2020-08-04 Layout Work on Rev 5
    [SmartWatch V5.kicad_pcb, SmartWatch V5.sch]
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2020-08-04 added potential fix for bug where smartwatch would hit play song button when going to sleep
    [Home.ino]
2020-08-04 PCB Routing for REV5
    [SmartWatch V5.kicad_pcb, SmartWatch V5.sch]
2020-08-04 Completed Rev 5 Board Layout and Routing
    [SmartWatch V4-B_Cu.gbr, SmartWatch V4-B_Mask.gbr, SmartWatch V4-B_Paste.gbr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]
2020-08-05 Restarted Layout To Improve overall board design
    [SmartWatch V5.kicad_pcb]
2020-08-05 Completed New Layout and Routing of Rev 5 (overall improved)
    [SmartWatch V5.kicad_pcb, SmartWatch V5.sch]
2020-08-05 Added additional capacitence where board space permits
    [SmartWatch V5.kicad_pcb, SmartWatch V5.sch]
2020-08-05 Final Touches to Board Design
    [SmartWatch V5.kicad_pcb]
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2020-08-05 Created new case design for Rev 5
    [Rev 5 Bottom.stl, Rev 5 Top.stl]
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2020-08-05 Added more space between the new case's top and bottom for a better fit
    [Rev 5 Top.stl]
2020-08-05 Changed ACCEL_EN to IO34
    [SmartWatch V5.kicad_pcb, SmartWatch V5.sch]
2020-08-05 Rerouted ACCEL_EN to IO34
    [SmartWatch V5.kicad_pcb, SmartWatch V5.sch]
2020-08-06 Experimenting with smaller 3D printed case design for Rev 5
    [Rev 5 Bottom.stl, Rev 5 Top.stl]
2020-08-07 Added CSV BOM and updated PDF Schematic
    [SmartWatch V5.csv]
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2020-08-08 Exported Gerber Files For Production
    [SmartWatch V5-B_Cu.gbr, SmartWatch V5-B_Mask.gbr, SmartWatch V5-B_Paste.gbr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]
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2020-08-10 Removed the majority of #ifdef DEBUG lines and replaced with function macro
    [CircularAnimation.ino, Home.ino, MainLoop.ino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]
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2020-08-11 Fixed an issue with BLE not working when DEBUG wasn't defined
    [BluetoothRecieve.ino, Declarations.h]
2020-08-11 Added "play spotify" functionality back to app menu and fixed bug with home screen play button
    [Apps.ino, BluetoothRecieve.ino, Declarations.h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]
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2020-08-15 Notifications on home screen should no longer display an extra "-" at the end
    [Home.ino]
2020-08-16 Calculator app no longer displays blank buttons
    [Calculator.ino]
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2020-08-19 Added More clearance between board and screen
    [Rev 5 Bottom.stl, Rev 5 Top.stl]
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2020-10-03 Modified 3D printed case to make the design more durable
    [Rev 5 Bottom.stl, Rev 5 Top.stl]
2020-10-03 Increased case to board spacing
    [Rev 5 Bottom.stl]
2020-10-03 Added path to case for battery wires. And made more room for LCD connector
    [Rev 5 Bottom.stl]
2020-11-04 corrected bug in settings menu causing multiple options to be selected from one touch
    [Settings.ino]
2020-12-22 Fixed multiple bugs with BLE connectivity in new firmware
    [Bluetooth.ino, Declarations.h, Smartwatch_Software_V2.ino]
2020-12-22 fixed bug in timekeeping and added background back in
    [Declarations.h, Smartwatch_Software_V2.ino, timekeeping.ino]
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2020-12-22 fixed bluetooth connection error
    [Bluetooth.ino]
2020-12-23 (maybe) fixed a crash caused by I2C conflict with FreeRTOS
    [Smartwatch_Software_V2.ino]
2020-12-31 fixed BLE connection issue
    [Bluetooth.ino]
2021-01-01 nvm last commit fixed BLE connection issue
    [Bluetooth.ino]
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2021-01-15 Animation circles no longer display overtop the notification text
    [Declarations.h, Smartwatch_Software_V2.ino, pages.ino]
2021-01-15 Re-added the selection window from the last version of the firmware (sometimes buggy still)
    [Declarations.h, Smartwatch_Software_V2.ino, TouchInterface.ino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]
2021-01-15 fixed accelerometer wakeup
    edit
    [Declarations.h, HardwareInterface.ino, Smartwatch_Software_V2.ino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]
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2021-01-16 device now periodically dips into deepsleep to manually reset the bluetooth peripheral
    [Smartwatch_Software_V2.ino]
2021-01-26 device will now reset after 3 wakes
    [Smartwatch_Software_V2.ino]
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2021-01-26 Changed V5 schematic to remove enable mosfet from accelerometer
    [SmartWatch V5-B_Cu.gbr, SmartWatch V5-B_Mask.gbr, SmartWatch V5-B_Paste.gbr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]
2021-02-04 fixed issue with notification reception and page displays
    [Bluetooth.ino, Smartwatch_Software_V2.ino, UI_Elements.ino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]
2021-02-04 removed "deep sleep reset" based on boot count
    [Bluetooth.ino, Smartwatch_Software_V2.ino]
2021-02-05 added touch cooldown to prevent accidental rapid touch
    [Declarations.h, HardwareInterface.ino, TouchInterface.ino]
2021-02-06 added non-blocking BLE receive option to allow data reception in the background (and some minor bug fixes)
    [Bluetooth.ino, Declarations.h, EEPROMSettings.ino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]
2021-02-06 fixed bug where BLE would connect but no commands could be issued
    [Smartwatch_Software_V2.ino]
2021-02-07 fixed bug where calendar would not open from navigation if BLE operation was in progress
    [pages.ino]
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2021-02-23 Fixed bugs relating to touch handling
    [Bluetooth.ino, Declarations.h, HardwareInterface.ino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]
2021-02-23 reverted experimental bluetooth code from last commit
    [Bluetooth.ino, TouchInterface.ino, pages.ino]
2021-02-24 watch will now reset when it enters sleep without a connection to reset the bluetooth peripheral.
    [Smartwatch_Software_V2.ino]
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2021-02-26 LCD Backlight will no longer flash after exiting deepsleep
    [Declarations.h, HardwareInterface.ino, Smartwatch_Software_V2.ino]
2021-03-02 Reworked accelerometer wakeup algorithim to reduce un-intended wakeups
    [Declarations.h, Smartwatch_Software_V2.ino]
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2021-04-27 fixed bugs with the settings menu
    [Smartwatch_Software_V2.ino, pages.ino]
2021-04-27 pulled calculator in from previous firmware version (still buggy)
    [HardwareInterface.ino, TouchInterface.ino, UI_Elements.ino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]
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2021-04-27 changed background image and corrected calculator icon
    some improvements to touch
    [Declarations.h, HardwareInterface.ino, Smartwatch_Software_V2.ino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]
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2021-04-28 Resolved issue which resulted in occasional crashes when multiple threads attempted to access the I2C peripheral
    [HardwareInterface.ino, Smartwatch_Software_V2.ino]
2021-04-28 minor edits to lower case
    [Rev 5 Bottom.stl]
2021-05-02 framebuffer should no longer be drawn while screen is being updated
    [Smartwatch_Software_V2.ino]
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2021-05-05 corrected bug causing crash
    [Smartwatch_Software_V2.ino]
2021-05-15 Touch ISR is now disabled before sleep, resolving an issue where the watch could stay active and drain battery
    [HardwareInterface.ino, Smartwatch_Software_V2.ino, pages.ino]
2021-09-18 watch will now get time without turning on screen if there was a reset.
    [Smartwatch_Software_V2.ino]
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2022-04-24 improved deep sleep reset behavior.
    [HardwareInterface.ino, Smartwatch_Software_V3.ino]
2022-05-22 prevented swipe from activating buttons in its path
    [drawableManager.ino]
2022-06-20 fixes for icon transmission
    [Utilities.ino]
2023-10-29 created a new case design to improve durability
    [SmartWatch Rev 5 Case 2 Bottom.stl, Smartwatch Rev 5 Case 2 Top.stl]
2023-10-29 Fixed MTU size with android app and made app icons show black areas as transparent
    [Bluetooth.ino, Declarations.h, VisualElements.ino]

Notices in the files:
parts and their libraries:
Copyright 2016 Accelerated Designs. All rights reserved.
